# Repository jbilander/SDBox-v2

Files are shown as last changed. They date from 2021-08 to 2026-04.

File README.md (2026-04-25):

# SDBox v2
***
SDBox v2 for Amiga, hardware compatible with the new updated card-detect (insert/eject interrupt) firmware written by N.Ekström available here: https://github.com/niklasekstrom/amiga-par-to-spi-adapter

This version is superseded by the new SDBox-v3 here: https://github.com/jbilander/SDBox-v3
***

<br />
<a href="images/SDBox-v2_pic1.png">
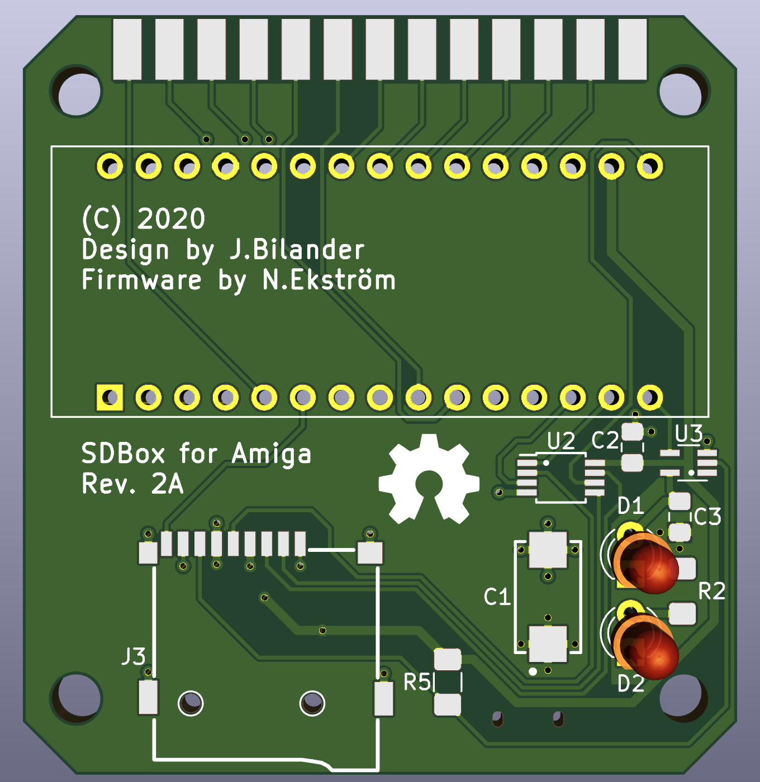
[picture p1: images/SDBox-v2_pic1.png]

</a>
<a href="images/SDBox-v2_pic2.png">
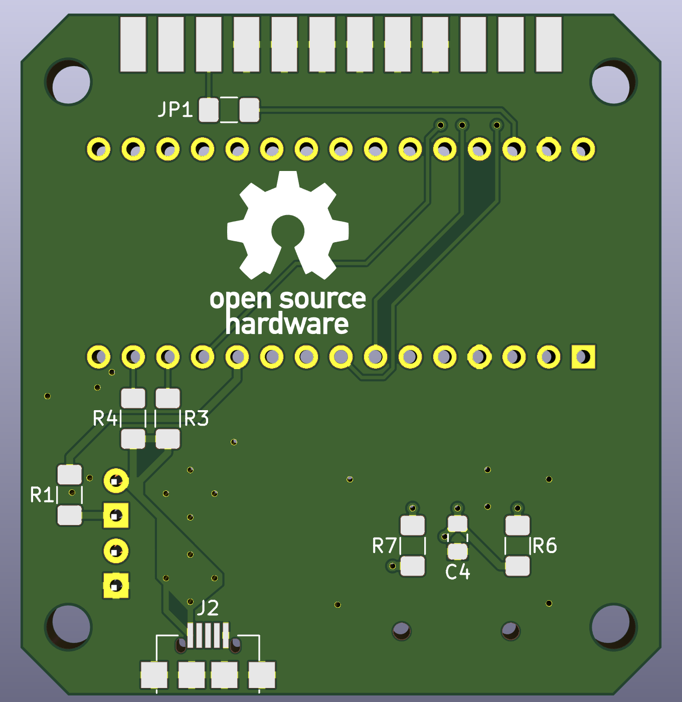
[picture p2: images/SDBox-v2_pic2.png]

</a>
<a href="images/SDBox-v2_pic3.png">
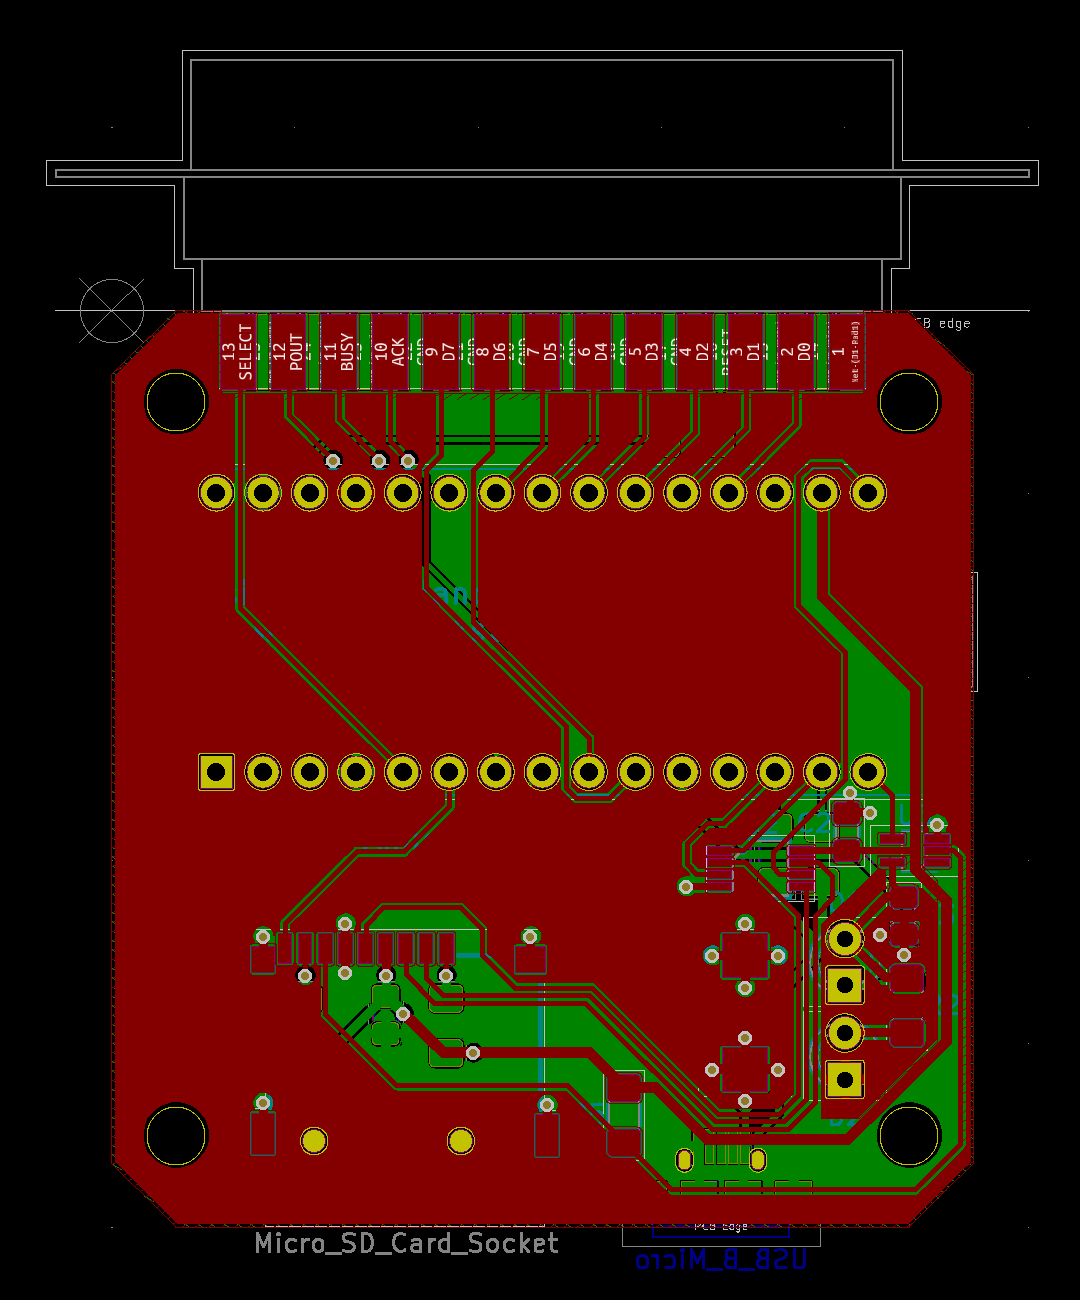
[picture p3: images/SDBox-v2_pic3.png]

</a>
<br />
<a href="images/SDBox-v2_pic4.png">
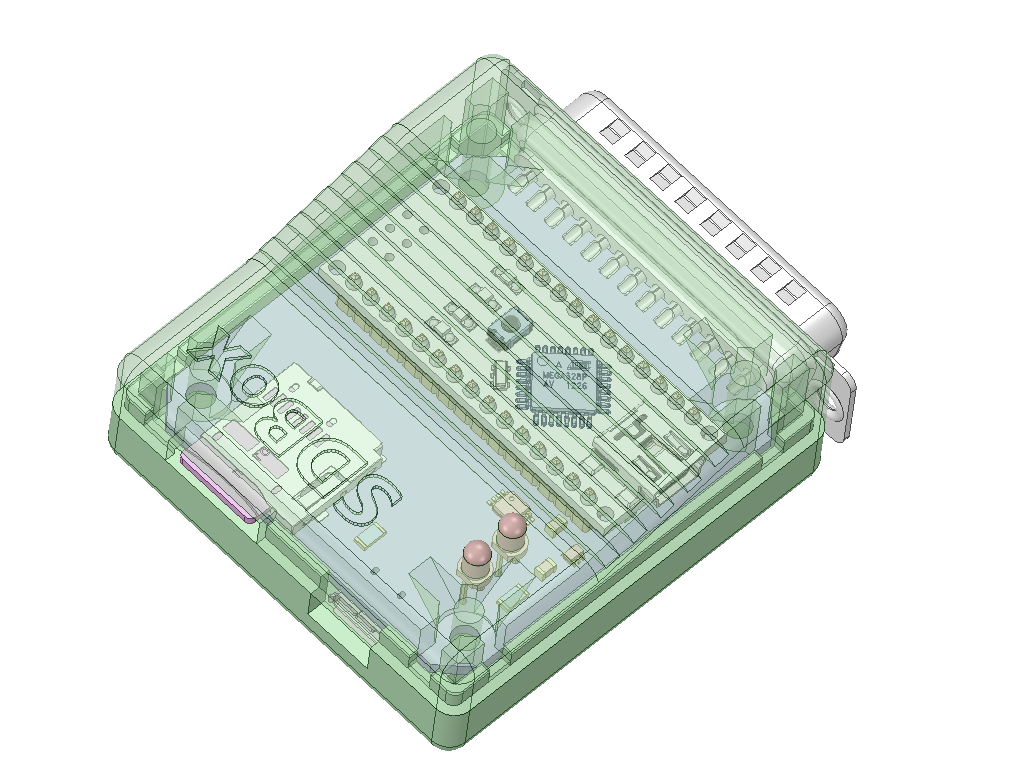
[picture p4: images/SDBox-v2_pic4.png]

</a>
<a href="images/SDBox-v2_pic5.png">
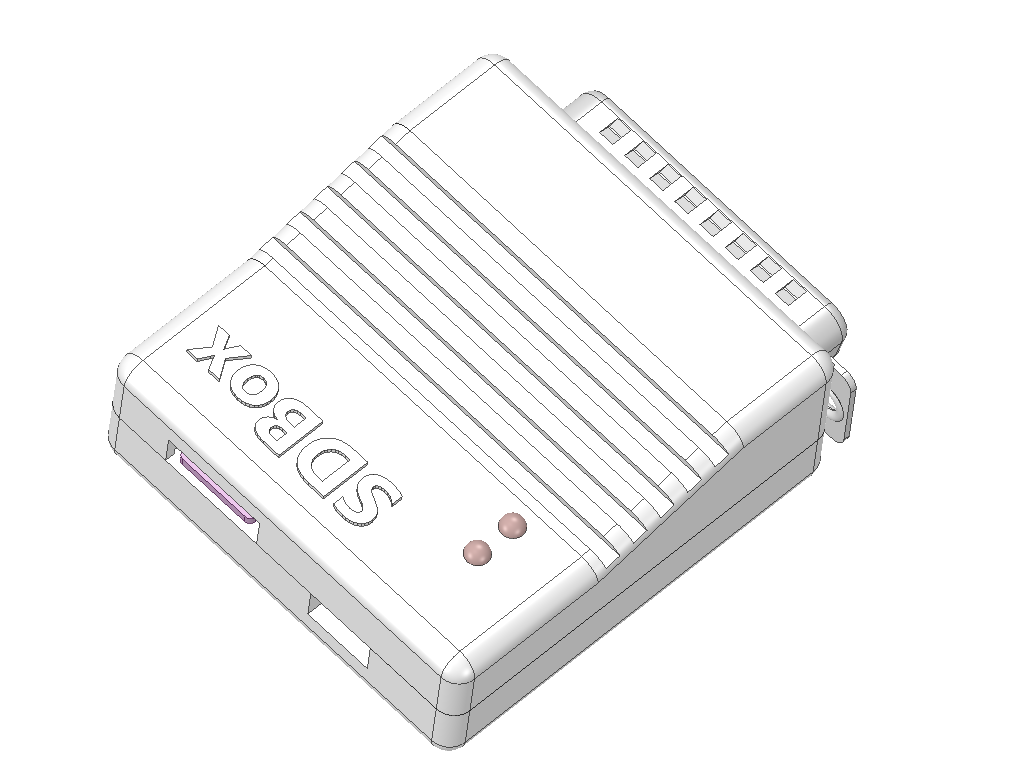
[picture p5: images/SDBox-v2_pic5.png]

</a>
<a href="images/SDBox-v2_pic6.png">
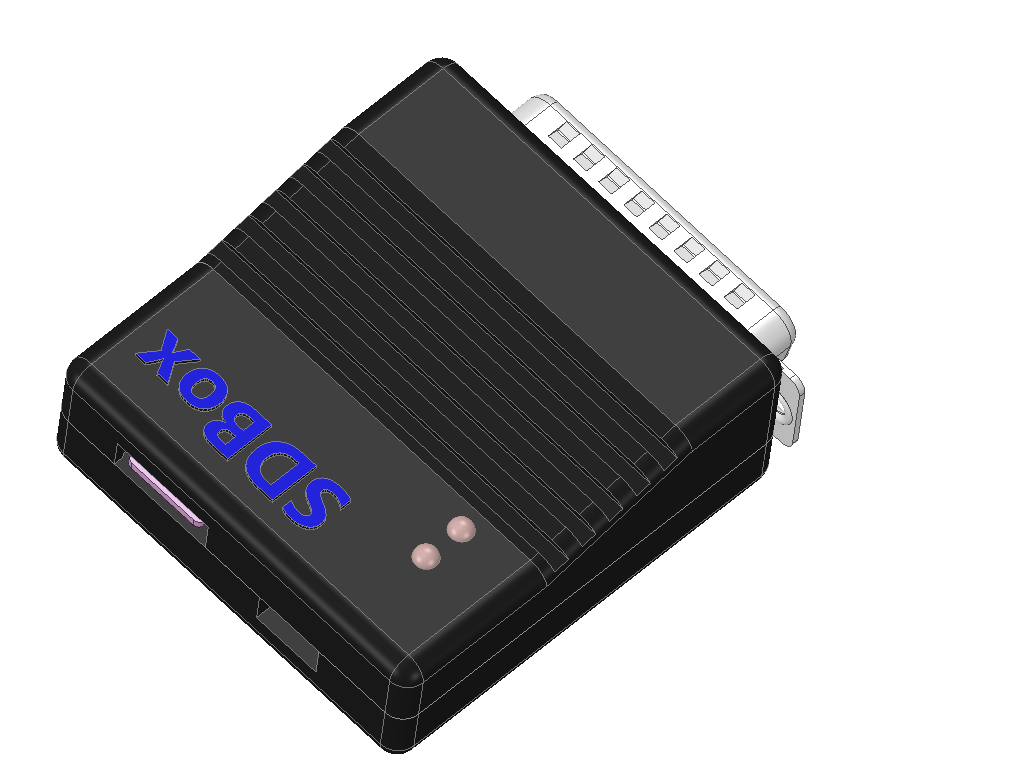
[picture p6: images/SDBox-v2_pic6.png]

</a>
<a href="images/SDBox-v2_pic7.jpg">
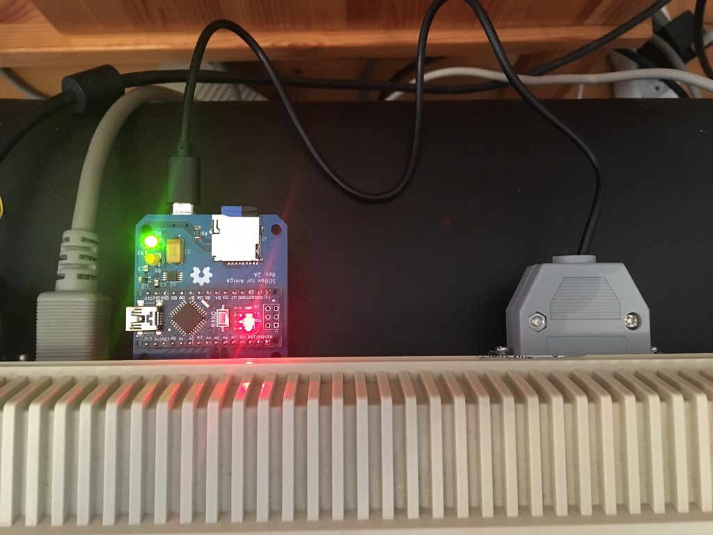
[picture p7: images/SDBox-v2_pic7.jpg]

</a>

***

Here is a short video clip showing the new card detect feature: <br />
https://drive.google.com/file/d/11R0idJcfvWwsGSfzbPFG1xpoupvCA6SC/view?usp=sharing

***

### Howto build the SDBox Rev2...

<a href="images/SDBox-v2_pic13.jpg">
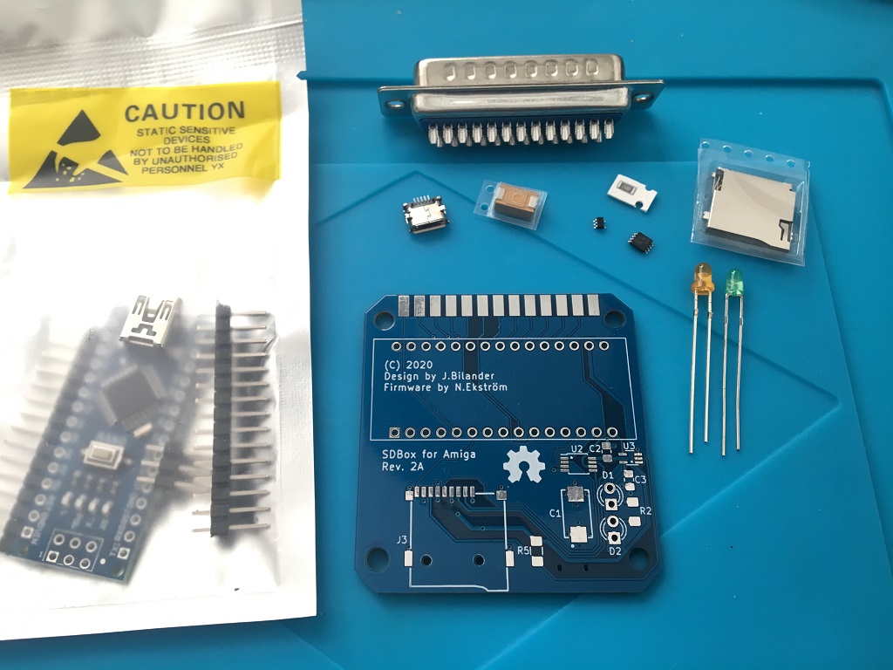
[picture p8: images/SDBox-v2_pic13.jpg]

</a>

***

Start by soldering the `U2` and `U3` ICs, then the passives, the card holder, micro-usb jack, DB25M and so on, nothing complicated, but do skip the 6-pin ICSP-header on the Nano if you're going to put this in a 3D-printed case...

***

<a href="images/SDBox-v2_pic14.jpg">
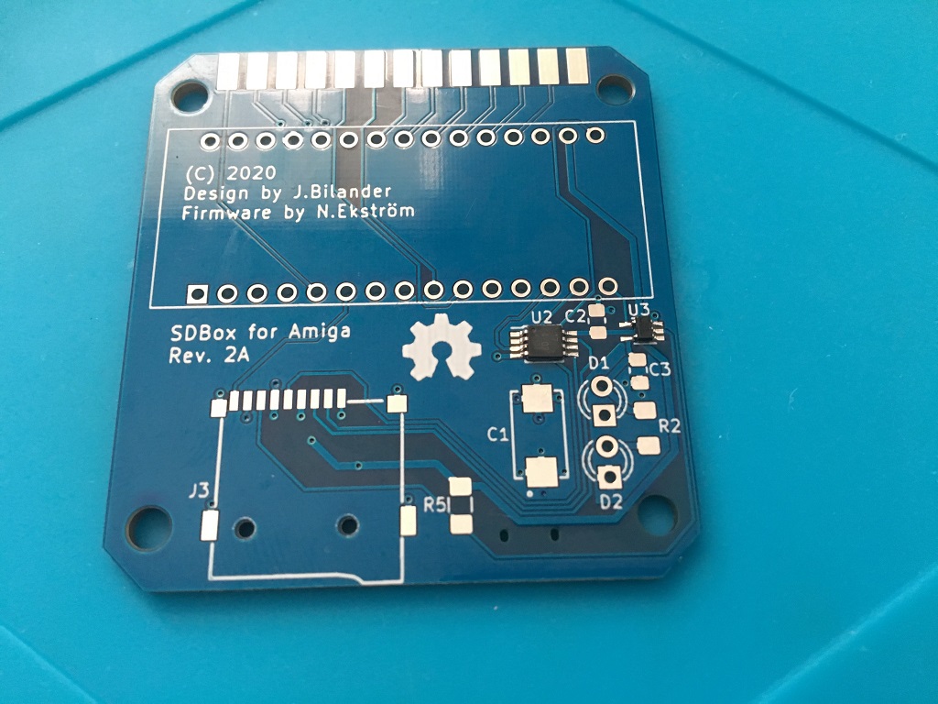
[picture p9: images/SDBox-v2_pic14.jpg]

</a>
<a href="images/SDBox-v2_pic15.jpg">
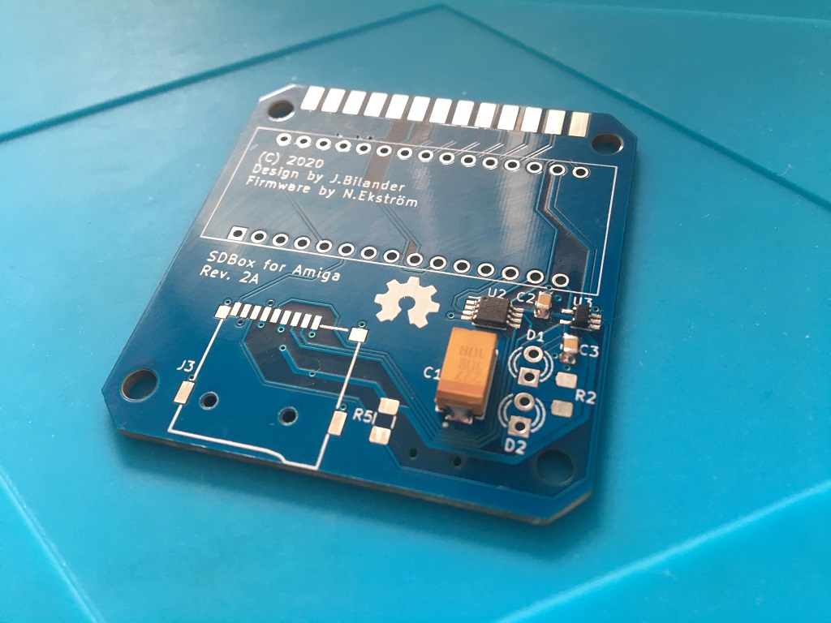
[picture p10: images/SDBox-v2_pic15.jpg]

</a>
<a href="images/SDBox-v2_pic16.jpg">
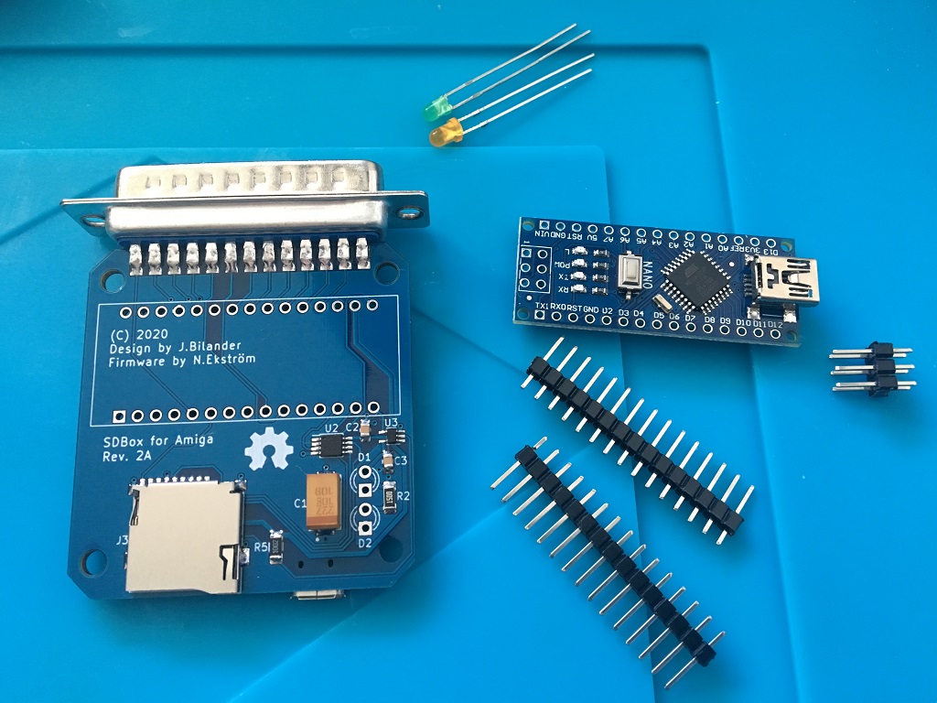
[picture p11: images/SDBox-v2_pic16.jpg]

</a>

***

At this stage, before you solder the Nano down to the board, you should verify that `+5V` via the Micro-USB jack is ok...

***

<a href="images/SDBox-v2_pic17.jpg">
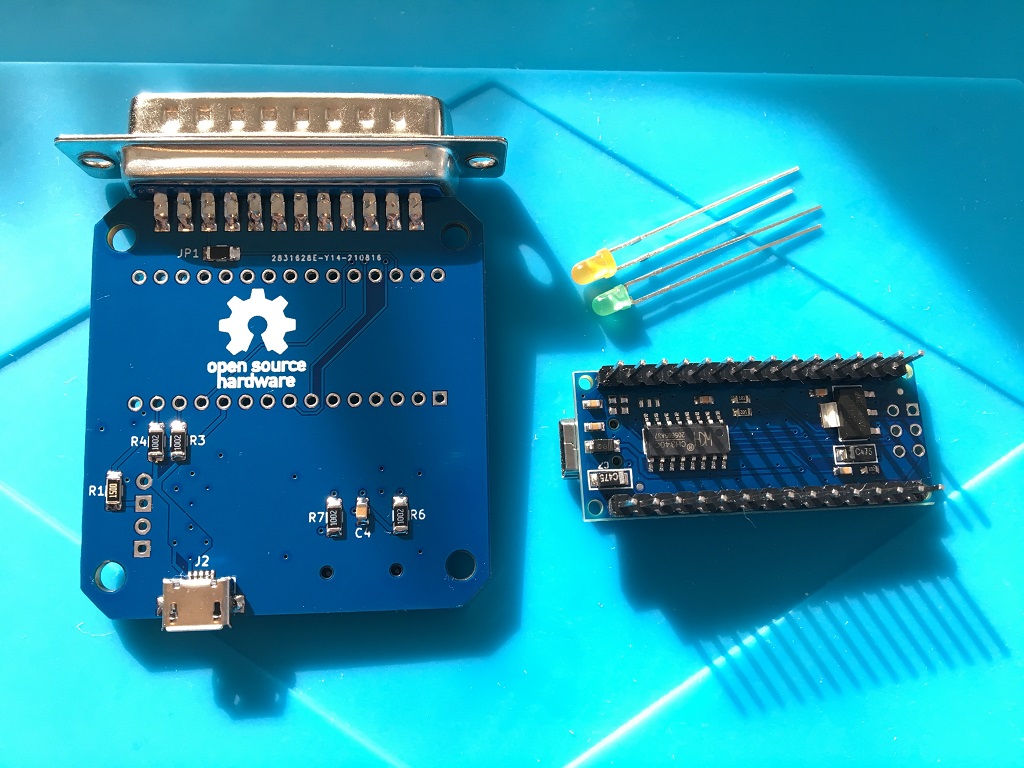
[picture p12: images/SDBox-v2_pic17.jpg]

</a>
<a href="images/SDBox-v2_pic18.jpg">
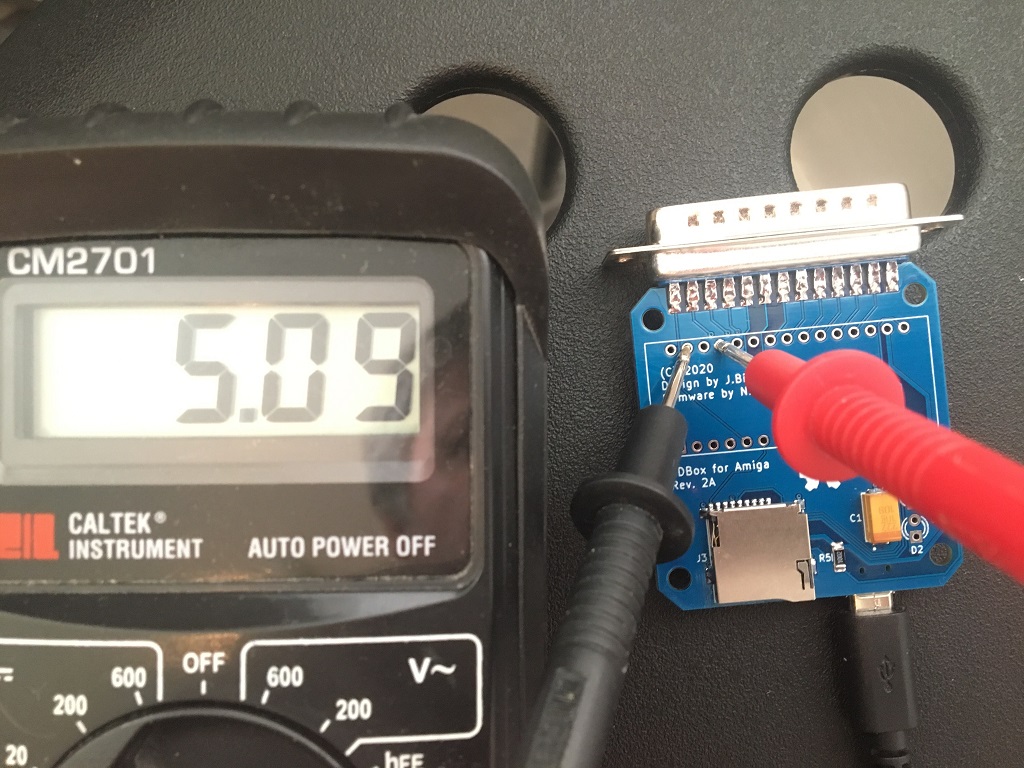
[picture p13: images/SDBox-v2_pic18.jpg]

</a>
<a href="images/SDBox-v2_pic19.jpg">
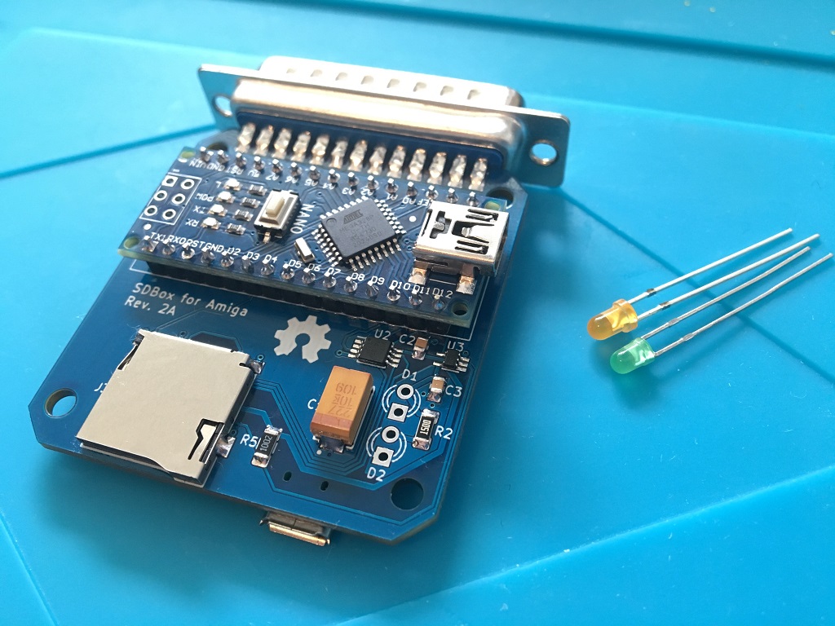
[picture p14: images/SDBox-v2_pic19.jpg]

</a>

***

Now the Nano, validate `+5V` and `+3.3V` is ok on the Nano:

Powering the MicroSD card directly from the 3.3V-pin of the Arduino, are you nuts?

Well, maybe, but typical SD card current consumption is `~30mA` in SPI mode.
The Arduino Nano taps `3.3V` from the internal LDO `3V3OUT` supply of the `FT232RL` USB-chip, or in case of the clones the `CH340` USB-chip. 

    FT232RL: Up to 50mA can be drawn from this pin to power external logic if required.
    CH340G: Maximum output current is 30mA, and that voltage stays rather stable up to about 30mA.
***

<a href="images/SDBox-v2_pic20.jpg">
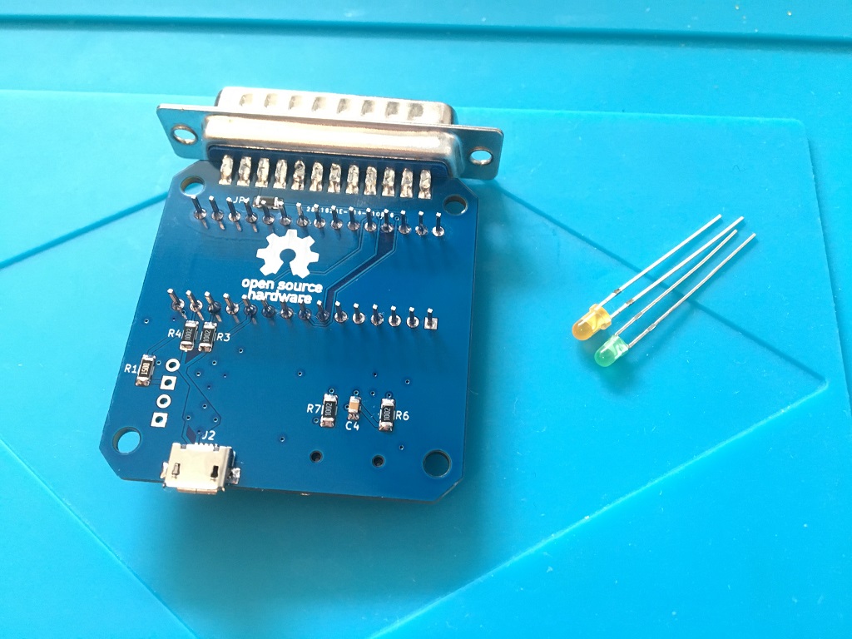
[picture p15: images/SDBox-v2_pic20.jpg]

</a>
<a href="images/SDBox-v2_pic21.jpg">
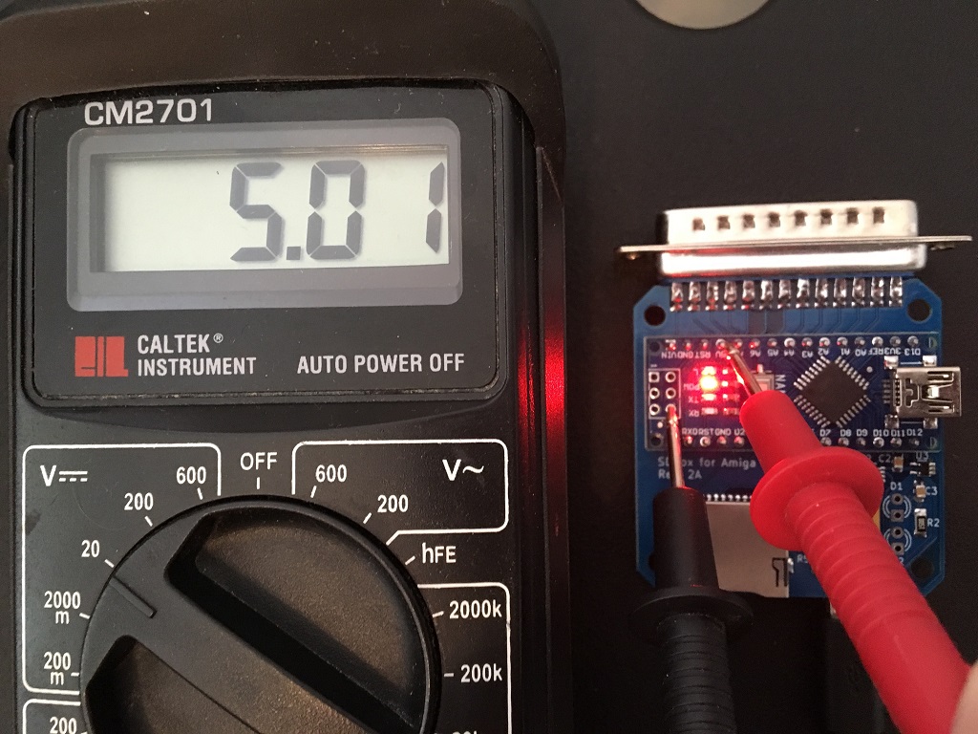
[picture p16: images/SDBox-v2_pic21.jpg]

</a>
<a href="images/SDBox-v2_pic22.jpg">
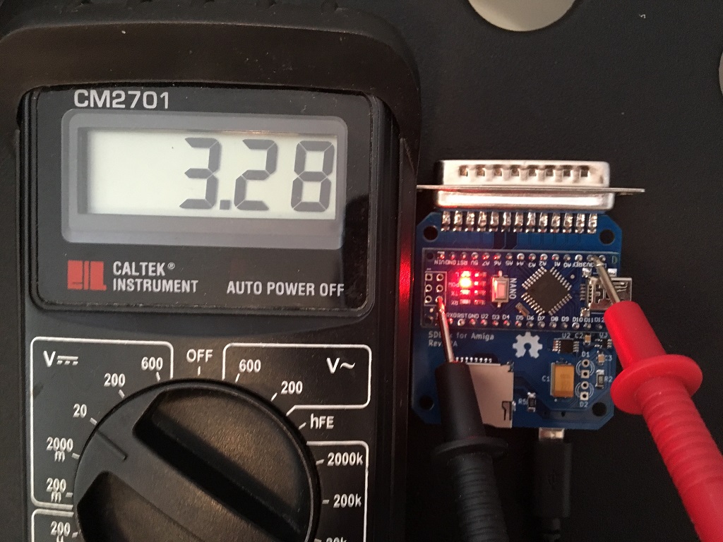
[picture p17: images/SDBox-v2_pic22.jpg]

</a>

***

Time to build and flash the firmware:

***

<a href="images/SDBox-v2_pic23.jpg">
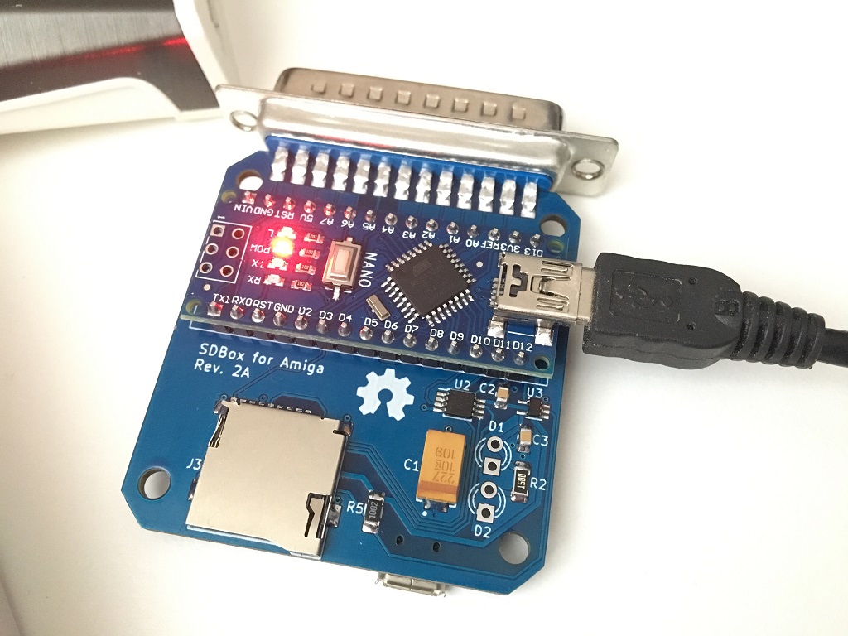
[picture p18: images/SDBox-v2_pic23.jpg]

</a>
<a href="images/SDBox-v2_flashing_Nano_pic1.jpg">
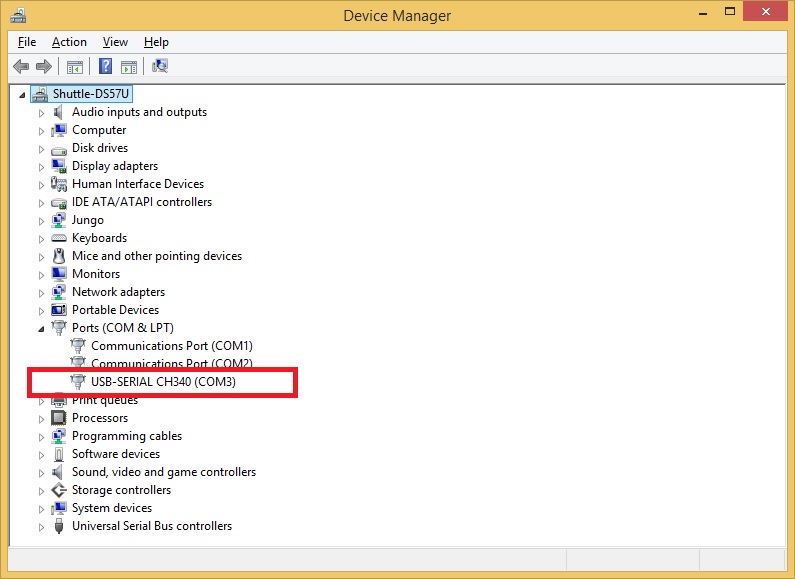
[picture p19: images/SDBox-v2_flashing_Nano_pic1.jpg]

</a>
<a href="images/SDBox-v2_flashing_Nano_pic2.jpg">
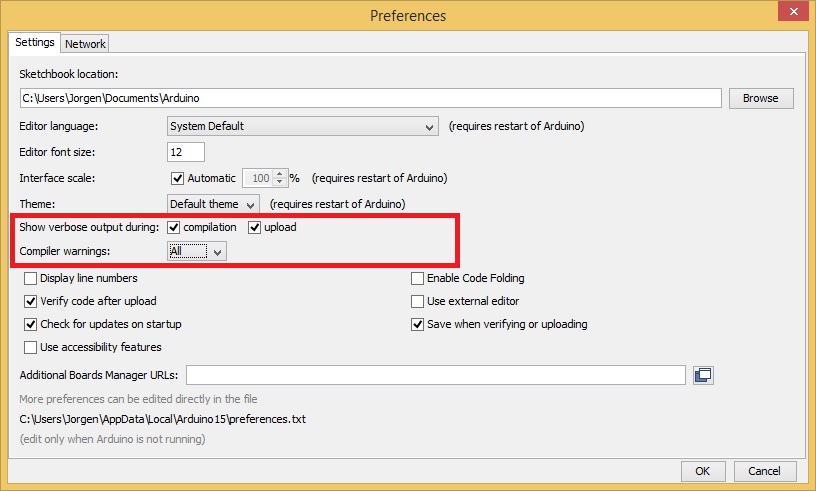
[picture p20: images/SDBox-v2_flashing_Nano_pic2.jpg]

</a>
<br />
<a href="images/SDBox-v2_flashing_Nano_pic3.jpg">
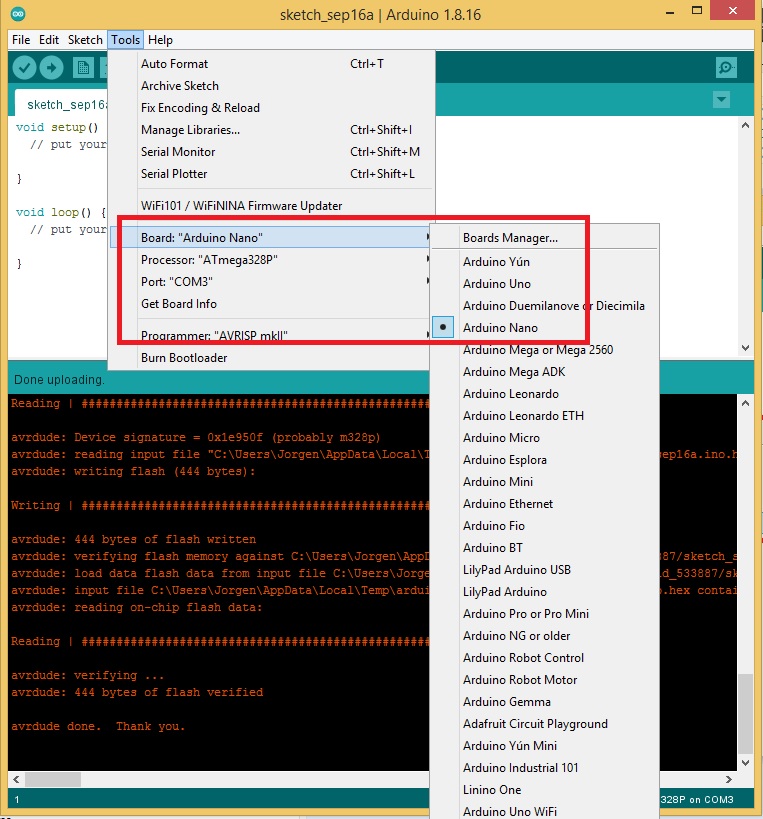
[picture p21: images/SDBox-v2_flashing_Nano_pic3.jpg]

</a>
<a href="images/SDBox-v2_flashing_Nano_pic4.jpg">
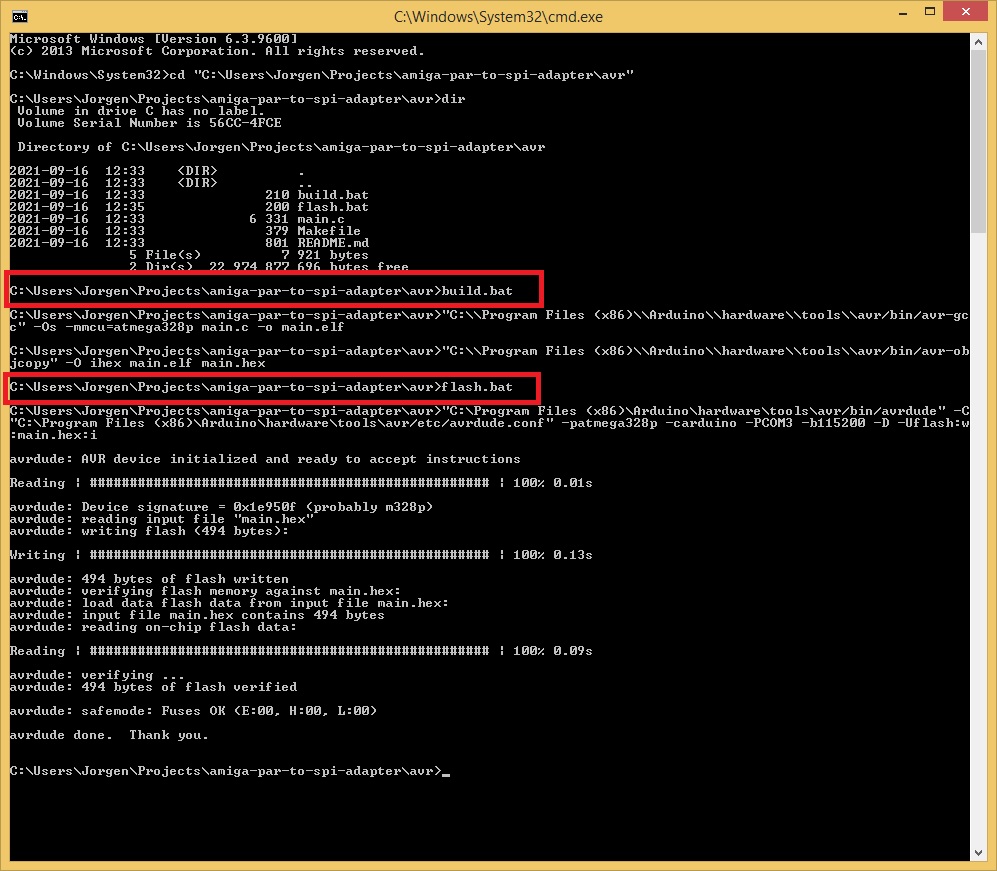
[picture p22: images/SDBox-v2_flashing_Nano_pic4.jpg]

</a>

***

And we need to 3D-print a case for it before we put the LEDs in, don't we?...

(STL-files available in the DSM folder)

***

<a href="images/SDBox-v2_pic24.jpg">
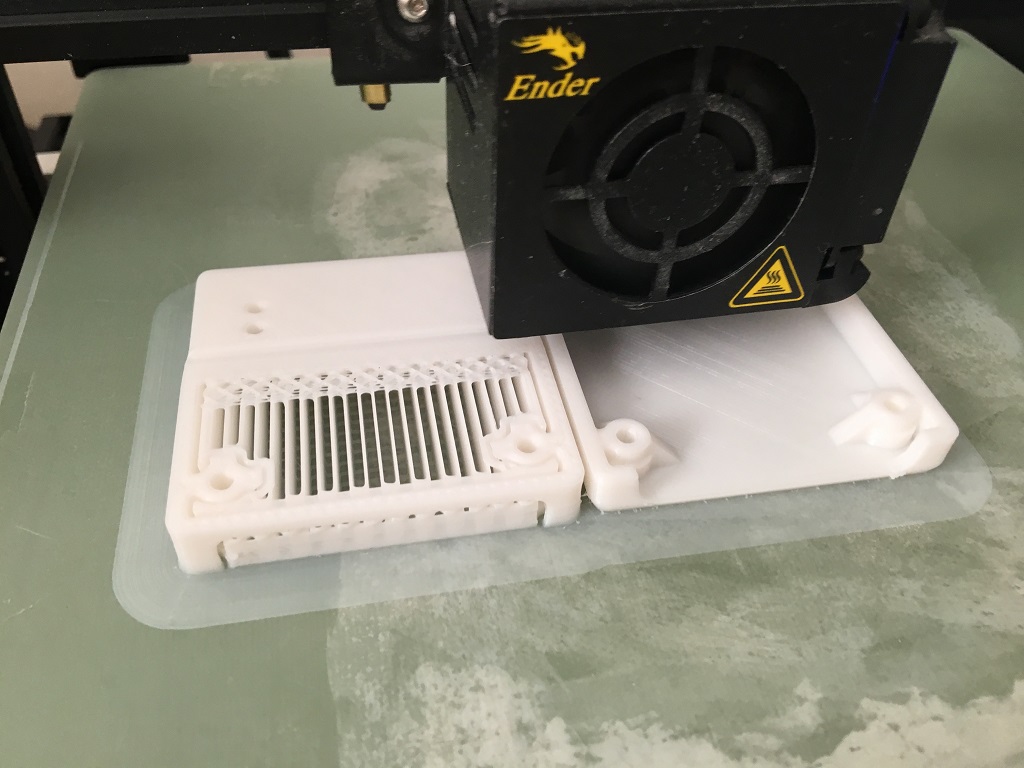
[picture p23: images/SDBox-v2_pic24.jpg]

</a>
<a href="images/SDBox-v2_pic25.jpg">
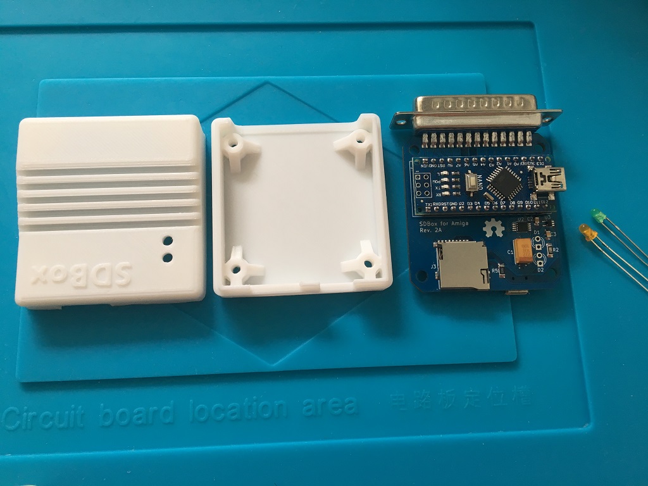
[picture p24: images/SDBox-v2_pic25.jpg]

</a>
<a href="images/SDBox-v2_pic26.jpg">
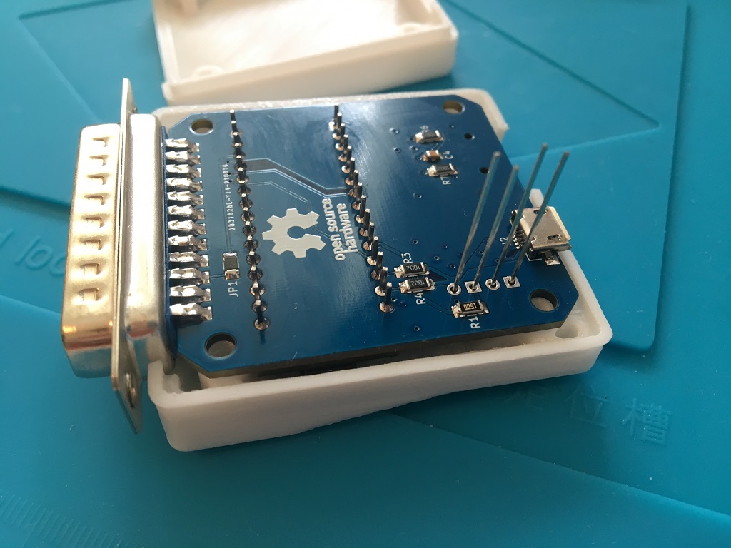
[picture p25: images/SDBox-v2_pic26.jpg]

</a>

***

Final result:
<br />
<a href="images/SDBox-v2_pic9.jpg">
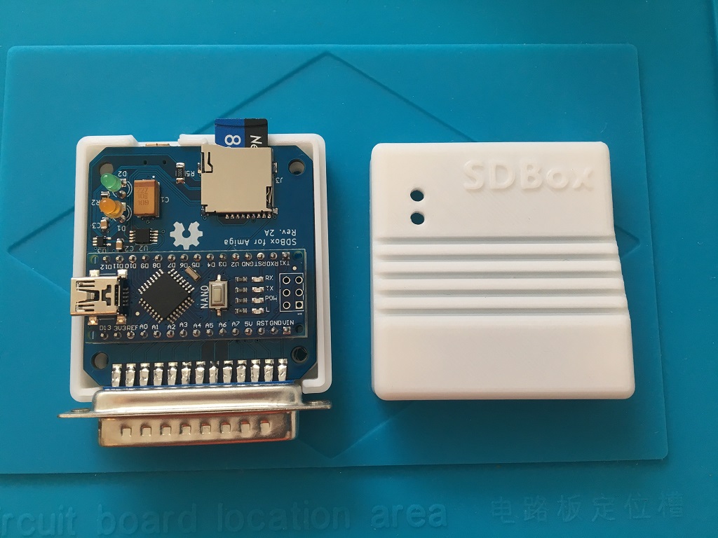
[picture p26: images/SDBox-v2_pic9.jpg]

</a>
<a href="images/SDBox-v2_pic10.jpg">
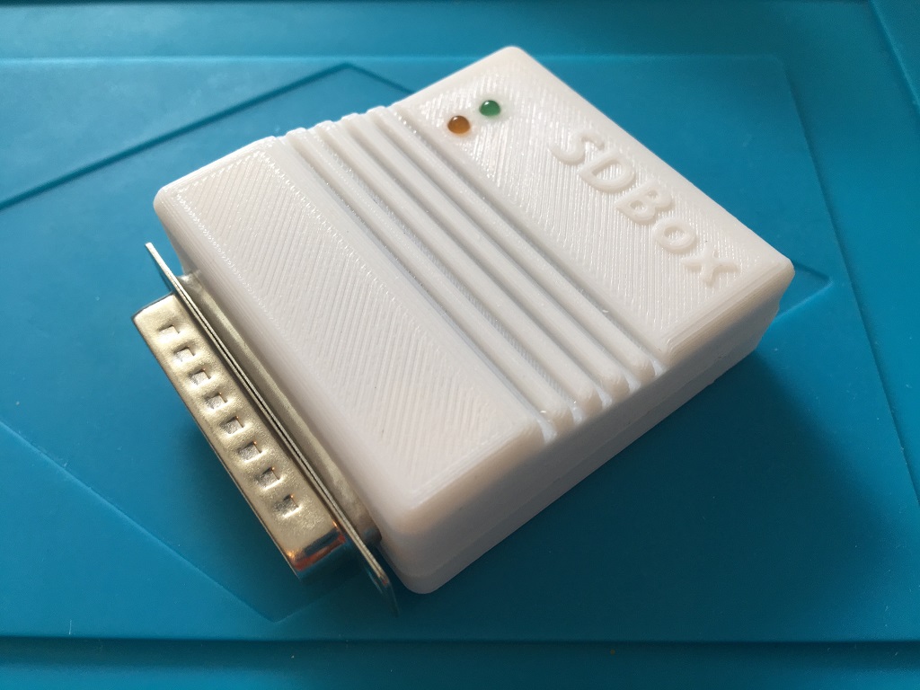
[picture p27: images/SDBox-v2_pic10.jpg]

</a>
<a href="images/SDBox-v2_pic11.jpg">
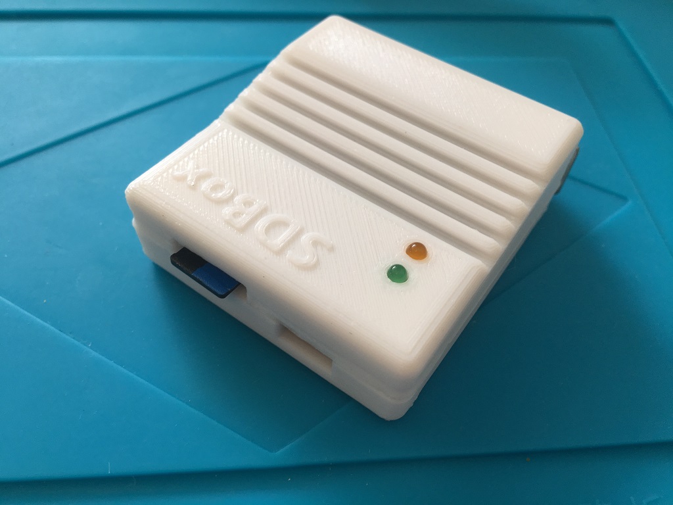
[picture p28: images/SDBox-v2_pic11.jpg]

</a>
<a href="images/SDBox-v2_pic12.jpg">
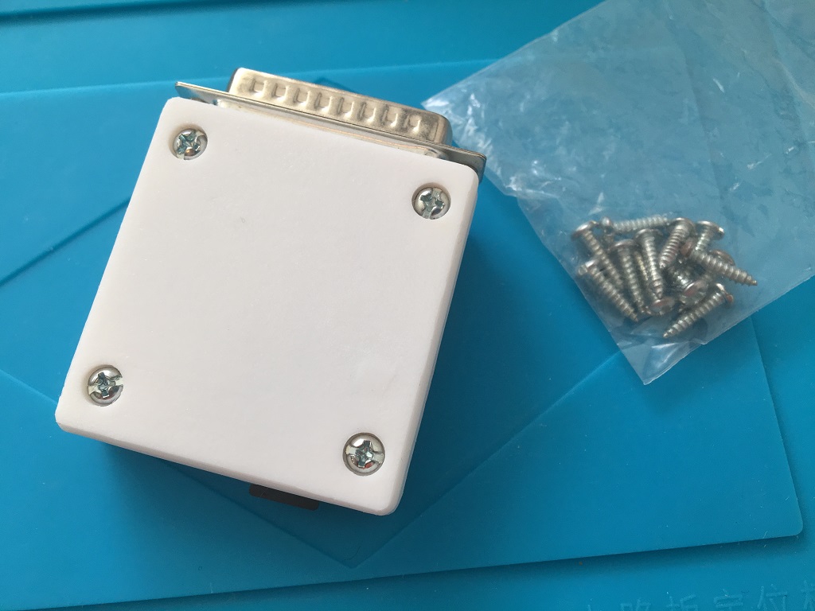
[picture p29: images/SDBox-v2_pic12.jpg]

</a>

***

Comparison with `v1`, look at the difference in size:
<br />
<a href="images/SDBox-v2_pic27.jpg">
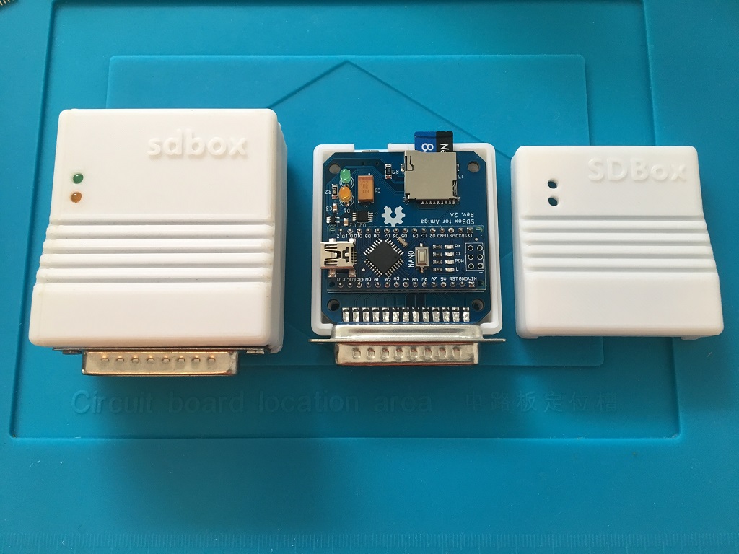
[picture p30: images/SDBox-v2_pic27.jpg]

</a>
<a href="images/SDBox-v2_pic28.jpg">
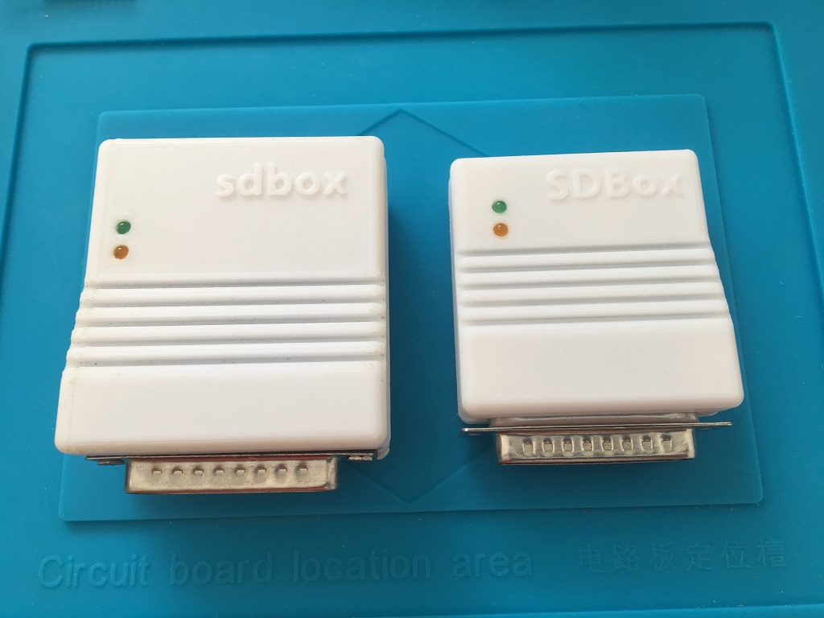
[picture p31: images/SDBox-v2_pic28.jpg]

</a>
<a href="images/SDBox-v2_pic29.jpg">
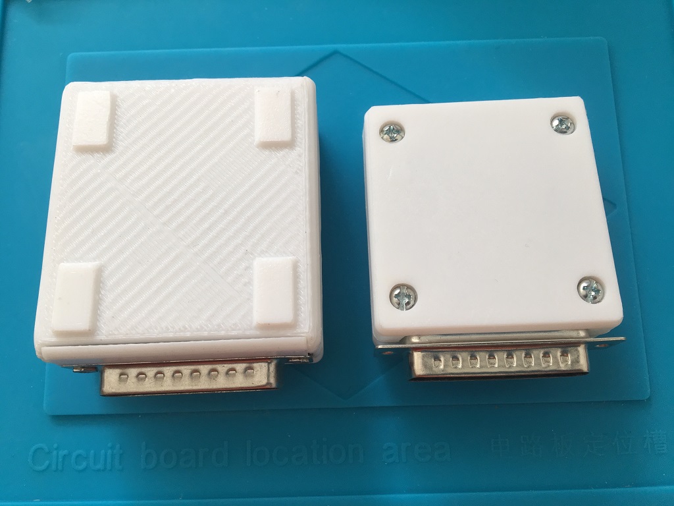
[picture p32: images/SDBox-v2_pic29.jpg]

</a>
<a href="images/SDBox-v2_pic30.jpg">
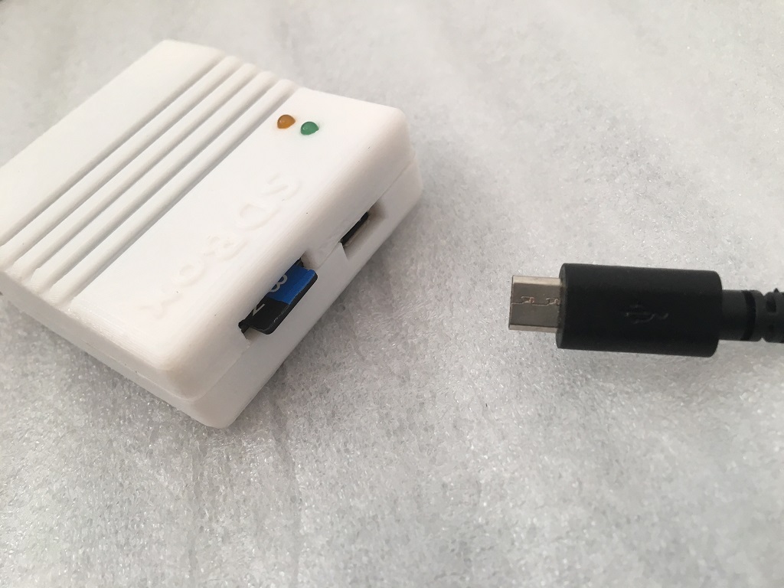
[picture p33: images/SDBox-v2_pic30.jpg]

</a>

***

Now time to build the new `spisd.device` driver, add `+kick13` to the `build.bat` if default is set to build for AmigaOS 2.0...

(`VBCC` for Windows I downloaded from here (Thanks: Leffmann for the installer), https://eab.abime.net/showthread.php?t=83113 )

***

<a href="images/SDBox-v2_VBCC_pic1.jpg">
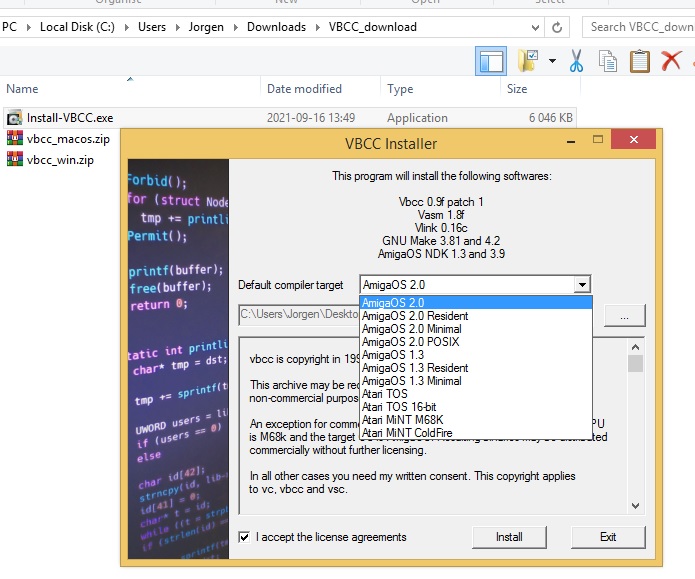
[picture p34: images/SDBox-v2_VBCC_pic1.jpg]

</a>
<a href="images/SDBox-v2_VBCC_pic2.jpg">
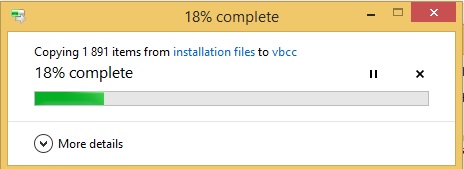
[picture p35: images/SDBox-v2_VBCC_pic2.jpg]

</a>
<a href="images/SDBox-v2_VBCC_pic3.jpg">
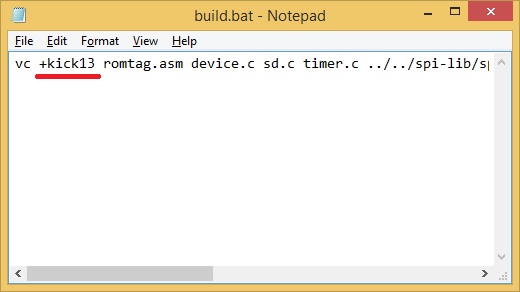
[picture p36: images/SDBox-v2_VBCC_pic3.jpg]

</a>
<a href="images/SDBox-v2_VBCC_pic4.jpg">
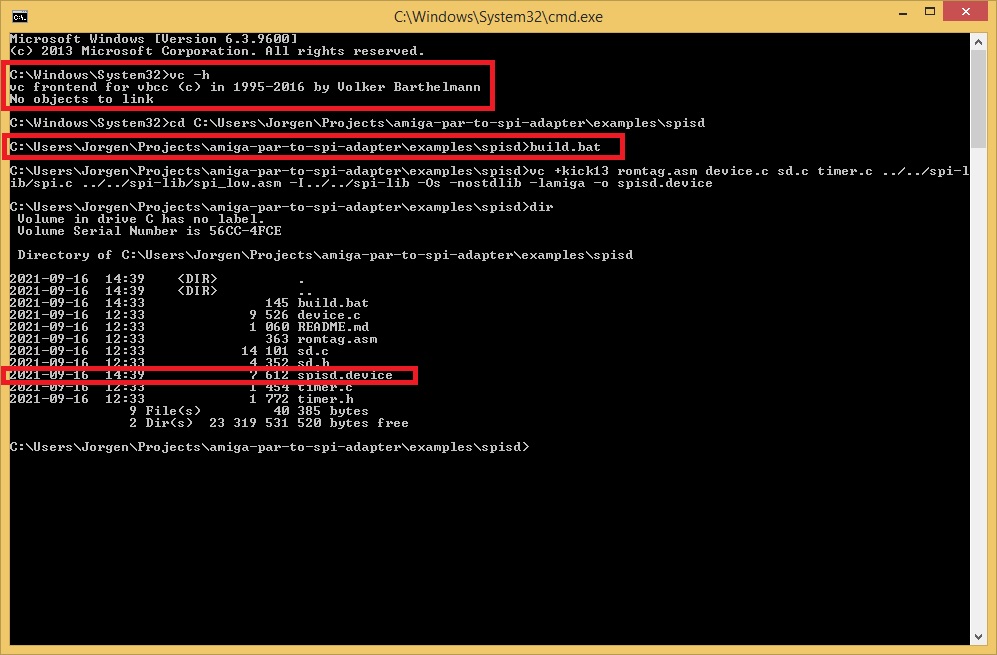
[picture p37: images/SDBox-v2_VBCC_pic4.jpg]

</a>

***

BOM Rev. 2A
---------
Position  | Name/Value   | Package | Notes
-|-|-|-|
U1 | Arduino Nano V3 | |
U2 | 74LVC3G17 | TSSOP-8_3x3mm_P0.65mm | Triple non-inverting Schmitt trigger with 5V tolerant input [74LVC3G17](https://www.mouser.com/ProductDetail/771-LVC3G17DP125)
U3 | 74AHCT1G17 | 5-TSSOP, SC-70-5, SOT-353  (2.0 mm × 1.25mm) | Single non-inverting Schmitt trigger [74AHCT1G17GWH](https://www.mouser.com/ProductDetail/771-74AHCT1G17GWH)
J1 | D-Sub DB25M | DB25 Male connector with solder lugs | DB25 for Amiga parallel port
J2 | Micro USB connector | USB Micro B SMT | For +5V Power, (style 1) <br />https://www.aliexpress.com/item/32991869539.html
J3 | Micro SD Card Holder | 9-pin Micro SD card slot connector | https://www.aliexpress.com/item/32802051702.html
D1 (Optional) | LED 3mm | PinHeader_1x02_P2.54mm_Vertical, pin pitch 2.54 mm | SD Activity LED indicator, Diffused Orange / Amber, 1.8V-2.3V, 20-30 mA, 605-610nm
D2 (Optional) | LED 3mm | PinHeader_1x02_P2.54mm_Vertical, pin pitch 2.54 mm | Power LED indicator, Green Diffused T-1, 25 mcd, 565 nm, 2.2 V, 25 mA
R1 (Optional) | 150 Ohm Resistor | 1206 SMD, 200 mW | (Mandatory if D1 populated) Series resistor for D1 LED, adjust R-value to your type of LED and preferred brightness
R2 (Optional) | 150 Ohm Resistor | 1206 SMD, 200 mW | (Mandatory if D2 populated) Series resistor for D2 LED, adjust R-value to your type of LED and preferred brightness
R3 | 10k Ohm Resistor | 1206 SMD | Pull-up (to VCC) resistor for /SS
R4 (Optional) | 10k Ohm Resistor | 1206 SMD | Pull-up (to VCC) resistor for MOSI
R5 | 10k Ohm Resistor | 1206 SMD | Pull-up (to 3V3) for MISO_3V3
R6 | 10k Ohm Resistor | 1206 SMD | Pull-up (to 3V3) for DAT1 pin 8 on MicroSD-holder
R7 | 10k Ohm Resistor | 1206 SMD | Pull-up (to 3V3) for DAT2 pin 1 on MicroSD-holder
JP1 (Optional) | 0 Ohm Resistor, or Solder Blob | 1206 SMD | Populate this one to reset Nano in conjunction with Ctrl-Amiga-Amiga
C1 | 220uF Capacitor | SMD-Tantalum, 4.3 x 7.3 x 2.8 mm | Capacitor for VIN +5V Power via USB https://www.reichelt.com/se/en/smd-tantalum-220-f-10v-125-c-t491d-220u-10-p206492.html
C2 | 0.1uF = 100nF Capacitor | 0805 SMD | Decoupling capacitor for U2
C3 | 0.1uF = 100nF Capacitor | 0805 SMD | Decoupling capacitor for U3
C4 | 0.1uF = 100nF Capacitor | 0805 SMD | Decoupling capacitor for J3

***

### Howto get 5V from the Amigas external floppy port _(250 mA max)_, let's make a cable...

<br />
<a href="images/SDBox_get_5V_from_external_floppy_port_cable_pic1.jpg">
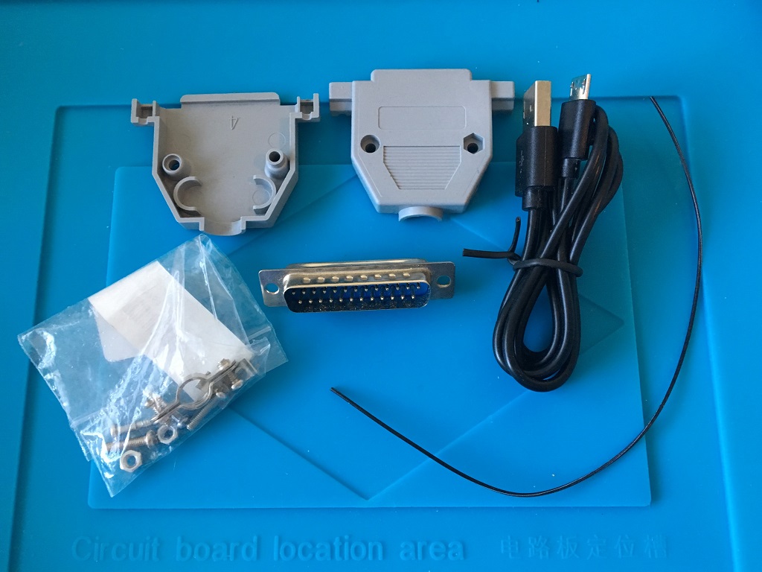
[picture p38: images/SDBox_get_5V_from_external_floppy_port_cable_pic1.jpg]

</a>
<a href="images/SDBox_get_5V_from_external_floppy_port_cable_pic14.jpg">
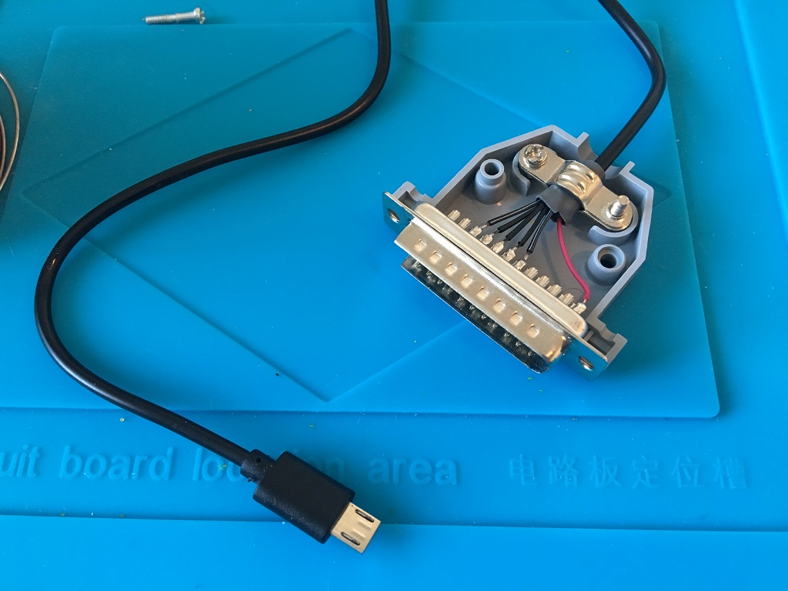
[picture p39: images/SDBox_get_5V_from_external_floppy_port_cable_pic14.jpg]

</a>
<a href="images/SDBox_get_5V_from_external_floppy_port_cable_pic15.jpg">
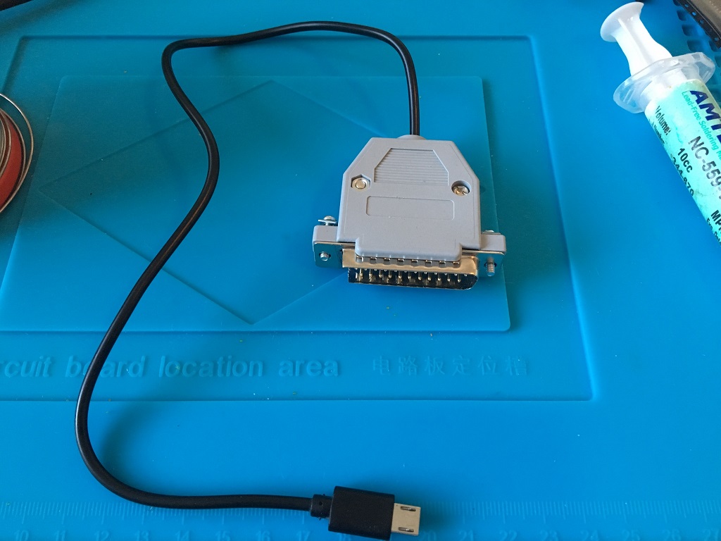
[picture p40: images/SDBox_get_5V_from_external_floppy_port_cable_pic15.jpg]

</a>

***
I did't have a `DB23` Male connector so I used a `DB25` and cut it down to a 23 with a hacksaw. I cut on the left side (pin 1 and 14) so that the plug will clear the neighbouring RCA-jack when plugged into the A500 external floppy drive port.
***

<a href="images/SDBox_get_5V_from_external_floppy_port_cable_pic2.jpg">

</a>
<a href="images/SDBox_get_5V_from_external_floppy_port_cable_pic3.jpg">

</a>
<a href="images/SDBox_get_5V_from_external_floppy_port_cable_pic4.jpg">

</a>

***
Remove pin 1 and 14, wiggle back and forth with a plier until they exhaust and snap then pull out the remains from the other side
***

<a href="images/SDBox_get_5V_from_external_floppy_port_cable_pic5.jpg">

</a>
<a href="images/SDBox_get_5V_from_external_floppy_port_cable_pic6.jpg">

</a>
<a href="images/SDBox_get_5V_from_external_floppy_port_cable_pic7.jpg">

</a>

***
Cut and wirestrip the micro-usb cable. Verify polarity, normally black is GND and red is +5V but the cable mfg might have mixed up the wire colours so check with a multimeter to be certain. Pin 3-7 on the connector is GND on the Amiga, +5V is on pin 12. You could either Blob pin 3-7 together (requires quite a lot of solder) and then solder the micro-usb GND-wire to that Blob or do as I did below with 5 individual wires soldered and crimped together.
***

<a href="images/SDBox_get_5V_from_external_floppy_port_cable_pic8.jpg">

</a>
<a href="images/SDBox_get_5V_from_external_floppy_port_cable_pic9.jpg">

</a>
<a href="images/SDBox_get_5V_from_external_floppy_port_cable_pic10.jpg">

</a>

***
Some shrink tube on, a bit overkill maybe but hey it's a guide, no shortcuts, I even crimped AND soldered the GND-joint :)
***

<a href="images/SDBox_get_5V_from_external_floppy_port_cable_pic11.jpg">

</a>
<a href="images/SDBox_get_5V_from_external_floppy_port_cable_pic12.jpg">

</a>
<a href="images/SDBox_get_5V_from_external_floppy_port_cable_pic13.jpg">

</a>

***
Ready to go and it clears both the RCA-plug and the serial port connector. With this cable now plugged into the SDBox it'll be powered on as soon as the Amiga is powered on and vice versa.
***

<a href="images/SDBox_get_5V_from_external_floppy_port_cable_pic14.jpg">

</a>
<a href="images/SDBox_get_5V_from_external_floppy_port_cable_pic15.jpg">

</a>
<a href="images/SDBox_get_5V_from_external_floppy_port_cable_pic16.jpg">

</a>

***

Happy Hackin'

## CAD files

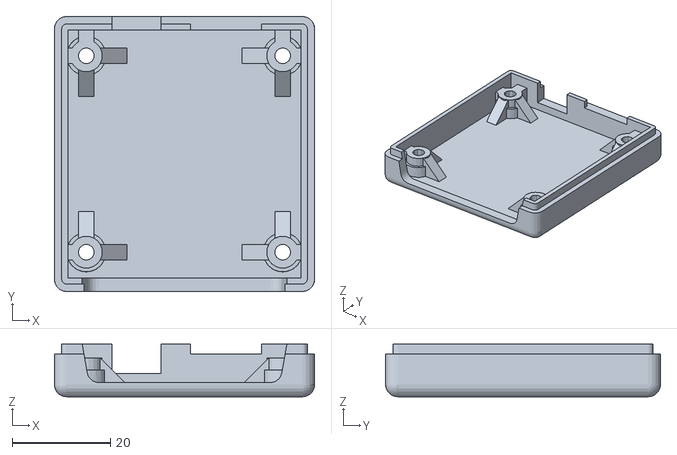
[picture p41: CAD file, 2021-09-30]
DSM/SDBox-v2_case_bottom.stl
53.0 x 56.0 x 10.7

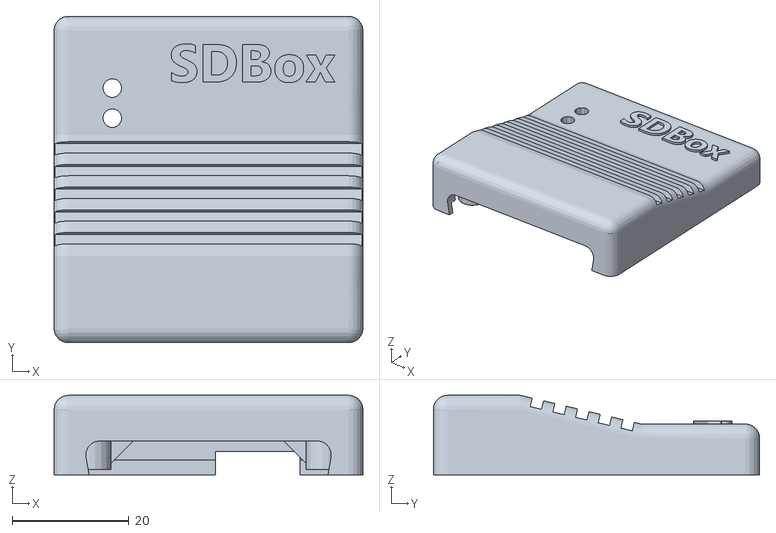
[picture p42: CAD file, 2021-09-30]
DSM/SDBox-v2_case_top.stl
53.0 x 56.0 x 13.6

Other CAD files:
DSM/SDBox-v2_text.skp

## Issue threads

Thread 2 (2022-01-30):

Firmware issues

hickachu, 2022-01-30:
When I use your firmware 0.4 hex or compiled from your fork, I am unable to mount the sd0. I get no error from the mount command but when I try to access sd0: I get "Bad number" error from the amiga. If the sdcard is in the sdbox v2 from cold boot the machine goes into a reset boot loop.
I see no activity from the nano when the sdcard is inserted or ejected.

When I use original firmware from Niklas Ekström the sdbox V2 works as it should, minus any activity light for obvious reasons.

I have built several of the units and it is the exact same on all units. Any idea what the "issue" could be?

jbilander, 2022-01-30:
Hi,

Firmware v0.4 is for the old sdbox Rev 1. It's not compatible with Rev 2, pinout assignments is different on Rev 2...You can use my fork of Niklas's firmware to build a hex with support for activity led for v2:

https://github.com/jbilander/amiga-par-to-spi-adapter

Regards, J

hickachu, 2022-01-30:
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

Sorry, I should have mentioned I did try that version, same results.

jbilander, 2022-01-30:
Hi, you mentioned it works with Niklas' firmware. My fork is the exact same code as his except these lines are added to enable the activity led.

https://github.com/jbilander/amiga-par-to-spi-adapter/commit/aeaf351bd57fc0b75dae18e1f8b91ef14cbc8c00

Retro-updates, 2022-05-04:
Hello, I'm getting SD0: Unreadable after mounting on AmigaOS. (Rev 2A SDBox with new spisd.device driver)
What  could i be doing wrong here?

jbilander, 2022-05-04:
Hi, did you build and flash the Arduino Nano with the updated firmware from here?
https://github.com/jbilander/amiga-par-to-spi-adapter/tree/master/avr

Retro-updates, 2022-05-04:
I programmed the nano with the v2 firmware;

Retro-updates, 2022-05-05:
> I programmed the nano with the v2 firmware;
> https://github.com/niklasekstrom/amiga-par-to-spi-adapter/releases/tag/v2.0
> and used the spisd.device from the same page

I programmed (make+flash) the nano with the v2 firmware;
https://github.com/niklasekstrom/amiga-par-to-spi-adapter/releases/tag/v2.0
and used the spisd.device from the same page

Retro-updates, 2022-05-05:
> Hi, did you build and flash the Arduino Nano with the updated firmware from here? https://github.com/jbilander/amiga-par-to-spi-adapter/tree/master/avr

I programmed (make+flash) the nano with the v2 firmware;
https://github.com/niklasekstrom/amiga-par-to-spi-adapter/releases/tag/v2.0
and used the spisd.device from the same page

jbilander, 2022-05-06:
Try with these files, they work for me, you need to copy to appropriate places...
[SDBox_v2_files.zip](https://github.com/jbilander/SDBox-v2/files/8638658/SDBox_v2_files.zip)

Retro-updates, 2022-05-06:
> Try with these files, they work for me, you need to copy to appropriate places... [SDBox_v2_files.zip](https://github.com/jbilander/SDBox-v2/files/8638658/SDBox_v2_files.zip)

Thanks. I have copied the files you've send to my wb3.1 environment, but when i launch SD0 mount icon, i get error message: 'SD0:' is not a valid keyword. (file 'SD0', line 1, comulm 1)

Retro-updates, 2022-05-07:
> Try with these files, they work for me, you need to copy to appropriate places... [SDBox_v2_files.zip](https://github.com/jbilander/SDBox-v2/files/8638658/SDBox_v2_files.zip)

At which moment do i need to see the activity led of the SDBox showing activity?
I only see the power led active at this moment.
The activity led is not on if i insert an SD or if i try to mount.

jbilander, 2022-05-07:
Hi, You need to build and flash the firmware from my fork if you want activity led support. I mention this in my first comment.
Activity LED will start to blink when you mount the drive. SD0-file is supposed to be placed into Devs-folder or you can change the location in the Mount-script and save the file, it does this:

```
cd devs:
mount SD0: from SD0
cd SD0:
quit
```

With KS 3.1/WB 3.1 and later I think you can remove the first line in the SD0-file (the SD0: part) and save the file, and then just double-click the SD0-icon to mount:

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

Retro-updates, 2022-05-07:
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

Thanks again for the information.
I've placed the SDO file in devs and removed the first line SD0:

Contents:
FileSystem     = l:fat95
Device         = spisd.device
Unit           = 0
Flags          = 0
LowCyl         = 0
HighCyl        = 0
Surfaces       = 1
BlocksPerTrack = 1
BlockSize      = 512
Reserved       = 0
Buffers        = 20
BufMemType     = 1
BootPri        = 0
StackSize      = 4096
Priority       = 5
GlobVec        = -1
DosType        = 0x46415401
#

When i try to mount SD0 from CLI i get error message: ERROR: Device 'SD0' not fond in file SD0

Retro-updates, 2022-05-07:
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

Additional information:
If i leave the SD0: to start the contents of the SD0 file, and use your fork to flash the nano, the activity led does go up a short moment when i mount the SD0. Only when i try to access it by going to the drive (CD SD0;) i get error message : Not a valid DOS disk. I've created a small <2GB partition on the MicroSD with Fat and Fat32)

jbilander, 2022-09-01:
Hi,

Salocinx has done some excellent SDBox-testing and found and fixed a bug in the V2-driver, you might want to try out if this fix helps with your issue as well.

This fix:
https://github.com/niklasekstrom/amiga-par-to-spi-adapter/commit/30736877bd1a5e277b54d2e37395fe8800dbba40

I have merged his fix (from upstream) into my fork as well now:
https://github.com/jbilander/amiga-par-to-spi-adapter

Regards

Retro-updates, 2022-09-01:
Thanks for sharing!
I will test the new driver and share my findings.

Retro-updates, 2022-09-02:
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

Do i need to compile the Amiga driver spisd.device only, or is a firmware flash for the arduino also needed?
Can you attach a compiled version of the driver here?

Retro-updates, 2022-09-07:
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

Flashed a arduino with v2 firmware for a SDBOX 2.
Used same amiga OS device driver.
MicroSD card is mounted correctly, but during write attemps i get write errors.
Is there a specific partition size for the Amiga advised?

jbilander, 2022-09-07:
Hi,
The fix is only on the Amiga side. You need to build a new _spisd.device_ and replace the one you have in Devs:
Instructions/pics for this is just above the BOM here https://github.com/jbilander/SDBox-v2/#bom-rev-2a
Firmware is the same as before.
Regards

Retro-updates, 2022-09-07:
> Hi, The fix is only on the Amiga side. You need to build a new _spisd.device_ and replace the one you have in Devs: Instructions/pics for this is just above the BOM here https://github.com/jbilander/SDBox-v2/#bom-rev-2a Firmware is the same as before. Regards

Thanks. Will build a new SPI.DEVICE driver for the Amiga and share results here.

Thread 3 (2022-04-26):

Provide Gerber files for PCB manufacturing services

germanviscuso, 2022-04-26:
Services like PCBway or JLCpcb expect Gerber file to start the PCB production, Can you provide them besides KiCad? Steps are here:
https://www.pcbway.es/helpcenter/technical_support/Generate_Gerber_file_from_Kicad.html
https://support.jlcpcb.com/article/44-how-to-export-kicad-pcb-to-gerber-files

jbilander, 2022-04-26:
Did you check under _Releases_ tab?

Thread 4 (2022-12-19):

Amiga 1000 issues

ami-commo-fan, 2022-12-19:
I already submitted on Nicolas par-to-spi page, but so far no response, so reporting here as well.
Does anyone succeeded to have working unit on Amiga 1000?
I have following issue running the adapter on the Amiga 1000.
The symptoms are the sdcard drive appears and disappears constantly for about 20 seconds and after is no longer accessible. All the time CPU usage is at maximum.
When using the same adapter on amiga with standard serial port, all works well.
I was checking the connections and all the signals needed are present on A1000 par. port so I do not understand why it is not working as expected.
Could that be similar driver issue that prevented working on A3000/4000 and was fixed lately?
I tried both 2.0 and 2.1 drivers both behave the same.

salocinx, 2022-12-20:
The problem on the A4000D was a timing issue (should be resolved in 2.1 release of the driver). The A3000D did not even initialize any MicroSD card without pull-up resistors on the parallel port data lines. Do you have pull-up resistors at the parallel port data lines in your specific SDBox?

Then, someone else reported a different issue with the A1000, some initialization issue. Finally he found out, that the 68010 CPU is incompatible with the current driver. Reverting to the original 68000 CPU resolved the issue. What CPU type you are using (68000 / 68010 or any accelerator) ?

I myself have tested the SDBox on the A1000 and I did not have any troubles with the latest driver revision 2.1, even without the pull-up resistors.

Does your SDBox has a female parallel port connector or do you use any intermediate adapter to connect a standard SDBox to the special A1000 male parallel port?

ami-commo-fan, 2022-12-20:
Actualy I made the sdbox for friend (with A1000). I built according the par-spi-scheme, so there is no pull-up resistors. I built with the female connector, but tested myself on my amigas (with gender-changer) and it worked. Of course I did not connect the +5V line which is different on both parallel ports. I expect he has a stock machine, but will let him know about the 010 incompatibility.
So I think good to try is the pull-ups. Is it 10k resistor from VCC (+5V) to each 2-9 dataline?

salocinx, 2022-12-20:
Yes, I pulled-up all the parallel port pins D0-D7, ACK, BUSY, POUT and SEL. But if I remember correctly, this was not needed on the A1000, only the A3000. Even the [SDBox v1](https://github.com/jbilander/sdbox) worked fine on the A1000. Jorgen later added level shifting ICs to the design in order to have a better translation between 3V3/5V for the SPI signals (MOSI/MISO/etc) between the SD card and ATMEGA micro controller (cp. [SDBox v2](https://github.com/jbilander/sdbox-v2)).

However, before you turn your hardware design inside out, I would first test with some other MicroSD card brands. I always made good experiences with SanDisk so far, lots of other brands currently don't work reliably. Maybe Jorgen can tell you what brand he used successfully (it was something other than SanDisk, but I cannot remember).

ami-commo-fan, 2022-12-20:
Ok, thanks for suggestions. The SDBox you tested ok with A1000 was just wired without the level shifter?

salocinx, 2022-12-23:
> Ok, thanks for suggestions. The SDBox you tested ok with A1000 was just wired without the level shifter?

As far as I remember, yes. I tested SDBox v1, which is without level shifter, and it worked on my A1000 with a SanDisk (4GB FAT/FAT16 partition).

jbilander, 2022-12-26:
On SDBox-v1 there is an IC on the SD Card Adapter-board that does the translation. I think it's an 74LVC125A that is fed with 3.3V. It might be that the MISO driven from the MicroSD drop too much to indicate a HIGH on the 74LVC125A or that the voltage level towards the ATMega is too low, however 3.3V should be enough for indicating a HIGH on the ATMega and also on the 74LVC125A. Anyway you have to put a pull-up resistor like SukkoPera did here:
https://github.com/jbilander/sdbox/issues/2#issuecomment-767763618

More info on the Catalex Micro SD Card Adapter here:
https://circuitstate.com/tutorials/interfacing-catalex-micro-sd-card-module-with-arduino/
https://forum.arduino.cc/index.php?topic=604921.msg4314215#msg4314215

Alectronics, 2023-08-05:
This v2B mini SDbox never worked reliable, not even with the newest drivers with the multilanguage FAT95 files on them.
After which my SD0: CF drive was gone and disabled.

So more trouble here sadly. Why I placed the old FAT95 back and removed that Mini micro SD Box driver  version. Its useless to try to fix something so unreliable.

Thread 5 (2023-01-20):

USB port - mechanical strength

SanguineBrah, 2023-01-20:
The location of the USB port on the underside of the board means that any cables hanging down are potentially levering the port away from the board and are in danger of ripping the pads right off the PCB (ask me how I know). A through-hole part would be stronger although I assume SMT was chosen to make routing easier. Another option would be to include slots either side of the port so that a cable tie could be used to secure it - it looks like this would only need one trace to be moved on the top side.

jbilander, 2023-01-20:
Hi, Yes there are some improvements that can be made, perhaps switch to a USB-C jack and also the SD-card holder could have been moved a bit further out on the PCB-edge so that it would be easier to grab hold of the MicroSD-card when you have the 3D-printed case on. However I currently have no need for more SDBoxes myself so right now that is not something I will do right now. It is open source so anyone who wants to improve the design can do so, but remember to share it back to the community afterwards.

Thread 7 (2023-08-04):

Build mini version 2B with smd components and Atmega328p chip. But all sd cards are No dos recognised!

Alectronics, 2023-08-04:
Only the card change is detected but never any transfer or data led activity visible. Only my green power led is always lit.
Tried every driver/boot version I could think of on my Amiga 1200 but the SD reader interface is very unreliable and never works as was expected. I also tried a 2GB fat and fat32 formatted original Sandisk microSD card same issue. No-dos disk.
Boards were made by PCBway according to the v2b gerber files but all was a waste of time and money.
Many other buyers/makers made this same comment. And the solutions given are always useless. After they gave up on this product!
This interface in case of these hopeless issues should have many more presented diagnostic info to check on like scope diagrams or logic analyzer diagrams to fix a not working interface.

Luckily my CF adapter interface always works splendidly to transfer files between my PC and Amiga. Including a perfect working internal CF Windows boot 'hdd'.

jbilander, 2023-08-05:
Hi, I have built several v2 and Mini devices with PCBs from JLCPCB and they all work perfectly fine with the latest fw and driver:

https://github.com/jbilander/amiga-par-to-spi-adapter/

There is no problem with the hardware. It has been tested by many people by now with the above firmware and it works even on a wirewrap thingie.

There has been reports of some MicroSD-cards not working properly and problems on the A1000.
https://github.com/niklasekstrom/amiga-par-to-spi-adapter/issues/8

And of course the usual thing with checking the CIAs with ATK and put pull-ups on the parallel-port control- and data-lines (required for some A3000 it seems)

_"This interface in case of these hopeless issues should have many more presented diagnostic info to check on like scope diagrams or logic analyzer diagrams to fix a not working interface."_

So why do you not make them? Remember this is an open source hobby project. Everything is there for anyone to dig in and help to improve it. Contribute nothing, expect nothing!

Alectronics, 2023-08-05:
Yes I understand but sorry Jorgen. I already wasted over 2 weeks figuring out why it won't work invain.

I even questioned the Amiga 1200 parallel port being defect why I also build today a parallel loop port tester and found out that it was working 100% fine!

So nothing is defect only the still not working v2B mini sd card reader/writer must be defect or badly designed.
Sadly I can't fix a problem that is made by others who obviously spended a lot of time to try to build such genious device that most of the time gives compatibility issues if it works!

Albert.

________________________________
Van: Jorgen Bilander ***@***.***>
Verzonden: zaterdag 5 augustus 2023 11:53
Aan: jbilander/SDBox-v2 ***@***.***>
CC: Alectronics ***@***.***>; Author ***@***.***>
Onderwerp: Re: [jbilander/SDBox-v2] Build mini version 2B with smd components and Atmega328p chip. But all sd cards are No dos recognised! (Issue #7)

Hi, I have built several v2 and Mini devices with PCBs from JLCPCB and they all work perfectly fine with the latest fw and driver:

https://github.com/jbilander/amiga-par-to-spi-adapter/

There is no problem with the hardware. It has been tested by many people by now with the above firmware and it works even on a wirewrap thingie.

There has been reports of some MicroSD-cards not working properly and problems on the A1000.
niklasekstrom/amiga-par-to-spi-adapter#8<https://github.com/niklasekstrom/amiga-par-to-spi-adapter/issues/8>

And of course the usual thing with checking the CIAs with ATK and put pull-ups on the parallel-port control- and data-lines (required for some A3000 it seems)

"This interface in case of these hopeless issues should have many more presented diagnostic info to check on like scope diagrams or logic analyzer diagrams to fix a not working interface."

So why do you not make them? Remember this is an open source hobby project. Everything is there for anyone to dig in and help to improve it. Contribute nothing, expect nothing!

—
Reply to this email directly, view it on GitHub<https://github.com/jbilander/SDBox-v2/issues/7#issuecomment-1666458075>, or unsubscribe<https://github.com/notifications/unsubscribe-auth/AUFU6ZFT2K7BMBLWEWJBBPDXTYJ3DANCNFSM6AAAAAA3EL755E>.
You are receiving this because you authored the thread.Message ID: ***@***.***>

jbilander, 2023-08-05:
So you need to do basic troubleshooting:

* Does the CIA work correctly with ATK (Amiga Test Kit)
* Is 5V-powering to the device looking good?
* Is 3.3V generated correctly to the MicroSD-card holder VCC-pin?
* Do you have activity on the MISO-line?
* Do you have activity on the MOSI-line?
* Do you have activity on the Parallel-port data and control lines? Pull-ups might be needed.
* Is the latest firmware flashed to the ATMega328p with fuses correctly set?
* Is the latest driver spisd.device put in the Devs folder on the Amiga?
* Is the correct version of the SD0 Mount file used for your WB-version on the Amiga?
* Is the latest fat95 driver copied to the Amiga?
* Does the 16 MHz clock looks ok going to the ATMega input pin?
* Do you have any solder bridges?
* Are you using a known good MicroSD-card?
* Does the device show the same error on another Amiga?
* Is the MicroSD-card properly FAT/FAT32-formatted?
etc, etc...

Alectronics, 2023-08-05:
Thanks for your fast reply Jorgen. But I thought my SDbox 2.b interface was complete and didn't need any pullups or modification?
What more do I also need to pullup because those smd 4R10K pullups were already on the miniSD reader board to accomplish that?

Albert.

________________________________
Van: Jorgen Bilander ***@***.***>
Verzonden: zaterdag 5 augustus 2023 12:34
Aan: jbilander/SDBox-v2 ***@***.***>
CC: Alectronics ***@***.***>; Author ***@***.***>
Onderwerp: Re: [jbilander/SDBox-v2] Build mini version 2B with smd components and Atmega328p chip. But all sd cards are No dos recognised! (Issue #7)

So you need to do basic troubleshooting:

  *   Does the CIA work correctly with ATK (Amiga Test Kit)
  *   Is 5V-powering to the device looking good?
  *   Is 3.3V generated correctly to the MicroSD-card holder VCC-pin?
  *   Do you have activity on the MISO-line?
  *   Do you have activity on the MOSI-line?
  *   Do you have activity on the Parallel-port data and control lines? Pull-ups might be needed.
  *   Is the latest firmware flashed to the ATMega328p with fuses correctly set?
  *   Is the latest driver spisd.device put in the Devs folder on the Amiga?
  *   Is the correct version of the SD0 Mount file used for your WB-version on the Amiga?
  *   Is the latest fat95 driver copied to the Amiga?
  *   Does the 16 MHz clock looks ok going to the ATMega input pin?
  *   Do you have any solder bridges?
  *   Are you using a known good MicroSD-card?
  *   Does the device show the same error on another Amiga?
  *   Is the MicroSD-card properly FAT/FAT32-formatted?
etc, etc...

—
Reply to this email directly, view it on GitHub<https://github.com/jbilander/SDBox-v2/issues/7#issuecomment-1666466628>, or unsubscribe<https://github.com/notifications/unsubscribe-auth/AUFU6ZGC2ZL4KJ2MABJRHGDXTYOTDANCNFSM6AAAAAA3EL755E>.
You are receiving this because you authored the thread.Message ID: ***@***.***>

jbilander, 2023-08-05:
pull-ups should not be needed on the A1200. I think it was required for the A3000.

https://github.com/jbilander/SDBox-v2/issues/4#issuecomment-1359937696
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
Alectronics, 2023-08-06:
I've thrown this crap product aside after the miniSDbox continuesly failed to work. And after all this time of wasted testing also the micro-usb connector broke of the tiny copper layers for the third time. Which probably wouldn't have happened if it finally was working and safely ready build in the DB25 connector case.

Those that got lucky with building this Amiga miniSDBox reader must have been extremely fortunate or they could find the right firmware for it because I never had so much trouble with finding the right firmware or getting a device working before!
And those people in the happy videos obviously got it ready tested including the properly working library files. Because to me and other buyers who also claimed their ready bought Amiga parallel port reader never worked it looks like this unfinished project was designed to fail.

________________________________
Van: Albert van bemmelen ***@***.***>
Verzonden: zondag 6 augustus 2023 00:16
Aan: jbilander/SDBox-v2 ***@***.***>
Onderwerp: Re: [jbilander/SDBox-v2] Build mini version 2B with smd components and Atmega328p chip. But all sd cards are No dos recognised! (Issue #7)

Sorry I already tried 6 different cards of which only one was microSD Sandisk 2GB. And the latter shortly worked with a lot of errors but now does nothing anymore.
My windows computers have no problem with reading any of them! Fat32 formatted. Only the miniSDbox v2b refuses to see them!

And sorry can't do anything with this info, since there is no driver FW =>

https://github.com/jbilander/amiga-par-to-spi-adapter

And I probably already tried all the versions 2 that had.

I'm pretty sure that it must be some software problem with the libraries or drivers. If it is not about port line pullups.

Albert.

________________________________
Van: Jorgen Bilander ***@***.***>
Verzonden: zondag 6 augustus 2023 00:04
Aan: jbilander/SDBox-v2 ***@***.***>
CC: Alectronics ***@***.***>; Author ***@***.***>
Onderwerp: Re: [jbilander/SDBox-v2] Build mini version 2B with smd components and Atmega328p chip. But all sd cards are No dos recognised! (Issue #7)

Well, if you have only tried ONE type of MiroSD-card and you say that card now does not even work in your PC or Mac. Maybe you should start thinking that it would be smart to try another card? Perhaps one listed here since they are verified to work. Makes me think you are not troubleshooting anything at all, just trolling.

jbilander/sdbox#15 (comment)<https://github.com/jbilander/sdbox/issues/15#issuecomment-1120407423>

The activity LED should work if you build from sources here:

Sorry can't do anything with this onfo, there is no driver FW =>

https://github.com/jbilander/amiga-par-to-spi-adapter

specifically this is the change:
***@***.***<https://github.com/niklasekstrom/amiga-par-to-spi-adapter/commit/aeaf351bd57fc0b75dae18e1f8b91ef14cbc8c00>

Niklas' code/release does not include code driving the activity LED. Anyway you should see activity on the MISO and MOSI lines and of course the parallel lines during MOUNT if you troubleshoot with a logic analyser or oscilloscope. I have already given you a list of what to start checking.

—
Reply to this email directly, view it on GitHub<https://github.com/jbilander/SDBox-v2/issues/7#issuecomment-1666620611>, or unsubscribe<https://github.com/notifications/unsubscribe-auth/AUFU6ZHBPLYGFGG3X7E6OVDXT27NTANCNFSM6AAAAAA3EL755E>.
You are receiving this because you authored the thread.Message ID: ***@***.***>

jbilander, 2023-08-06:
Not all people are made for DIY. Perhaps in your next life. Who knows, you might even be talented enough to run a bat file to compile a driver. Let's hope for that.

Alectronics, 2023-08-06:
Not all people present the ready and working upgrade firmware either LOL. Because all seen Github pages failed presenting those files. And the many firmware changes you previously showed made clear that only the insiders know what it is all about.
If I only knew  WHAT bat file is the correct REALLY working version? Because all previous boot disks and version 2 files completely failed working!
________________________________
Van: Jorgen Bilander ***@***.***>
Verzonden: zondag 6 augustus 2023 12:03
Aan: jbilander/SDBox-v2
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

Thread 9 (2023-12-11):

T

jbrandstetter, 2023-12-11:
Hi,

my overall goal is to be able to transfer larger files (i.e. larger than what fits on a floppy) to my Amiga.

So far I've tried CF to PCMCIA and the SDBox v2 but can't get neither to work.

My situation is as follows:

I have an Amiga 600 with:

*   3.1 RM, Kickstart 40.63, WB 40.42
*  a Furia accelerator
*   a 604N memory expansion
*  an internal Gotek
*  an SD2IDE Converter / Adapter
* an SDBox v2 from amigastore.eu powered by an external power source, with a supplied SD Card
* a plipbox ethernet adapter (which is working)
* a CF to PCMCIA adapter also from amigastore.eu

On the software side I have:

*   Installed the SDBox v2 drivers supplied by amigastore.eu
*   The following files in Devs/
    * compactflash.device
    * spisd.device
    * nothing in Devs/DOSDrivers/
*   FAT95 in L/
*   a Mountlist for SD0:

        FileSystem     = l:fat95
        Device         = spisd.device
        Unit           = 0
        Flags          = 0
        LowCyl         = 0
        HighCyl        = 0
        Surfaces       = 1
        BlocksPerTrack = 1
        BlockSize      = 512
        Reserved       = 0
        Buffers        = 20
        BufMemType     = 1
        BootPri        = 0
        StackSize      = 4096
        Priority       = 5
        GlobVec        = -1
        DosType        = 0x46415401

This mountlist is currently sitting in my "GAMES" partition. Then I do:

* mount GAMES:SD0 -> that works
* cd SD0: gives either "bad number" or the red light on the box lights up and Workbench is frozen

Any pointers on what I'm doing wrong?

Thanks,

Johannes

jbilander, 2023-12-11:
Hi, if their V2 is the same as my V2-design that works with Niklas' firmware I don't know since they don't share and follow the copyleft license. They should do the support at least when they take open designs without even giving a heads-up. I guess for them it's more important to make money. With that said there is a bugfixed driver here that has much better compatibility with different Micro-SD-cards now (thanks to Patrik) that you could try: spisd.device.zip ,or build your own from source.

https://github.com/niklasekstrom/amiga-par-to-spi-adapter/pull/9

jbrandstetter, 2023-12-11:
Oh wow, didn't know they were not playing nicely. Will consider that in the future. Thanks for the link to the other driver. Will give that a try!

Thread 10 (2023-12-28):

System hangs on Amiga 600 + classic Pistorm

Topaz750, 2023-12-28:
Hello,

I recently purchased the SDBox V2 from Amigastore.eu, but I'm encountering difficulties in getting it to function with my A600 Pistormed (Pi3A+). After installing the drivers, the system freezes during boot-up, indicated by a red light on the SDBox. I attempted using spisd.device version 2.3, but faced the same issue. My tests were conducted on a clean installation of AmigaOS 3.2.1, which was booted from the internal IDE port using a compact flash card, and also with Amikit V12 running from the PiStorm SD card.

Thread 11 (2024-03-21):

Missing newstyle.h

nbdy32, 2024-03-21:
HI, trying to build a new spisd.device, but there is a missing file ...

newstyle.h

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

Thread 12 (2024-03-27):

Access speed issue

martinpgrayson, 2024-03-27:
Hi all - bought a SDBoxV2 from Amigastore.eu. Its fantastic, such a cool device, thank you so much for creating it. Everything works, however, I just have a question about the initial speed when calling cd SD0: after mounting. On my Amiga 500 Rev6A it takes a long time, like between 1-2 minutes. I was wondering if there are things I can try. could it be the SDCard? I am using the drivers provided from this repo, but could it be those? Could it be my amiga?

My setup is very similar to the demo in this video:
https://www.youtube.com/watch?v=VQdrOjCI9As&t=75s

I have WB1.3 copied on to the SD card, and I followed these instructions to get it to boot to that copy:
https://exxosforum.co.uk/forum/viewtopic.php?t=6148

Before moving to booting WB1.3 from the SD card, I also tested with the Mount_SDCard script added do my WB floppy, just like this video:
https://youtu.be/mpZu9q7MV5I?si=iGDSSpGcRZjtWcR9&t=503

In the video, you can see it mounts an appears in about 20-30 seconds.

The last thing I noticed is that in other demo videos, when you eject the SD card, the drive disappears from the WB screen, and then reappears when you put the SD card back in - so it feels like I have done something wrong - wrong driver setup maybe?

Any help would of course be amazing, but I also appreciate this is already doing something clever, and it at least works, but would love to get the speed up just a bit.

jbilander, 2024-03-27:
Hi,

I have no affiliation with any Amiga store selling devices, nor does Niklas, and this is only a non-profit hobby project, so I'm not so keen on doing their support while they cash-in on sales not even giving a heads-up that they started making and selling devices, but what I can say is mounting the SD-Card should not take that long. Are you using the latest spisd.device driver built from here?
https://github.com/jbilander/amiga-par-to-spi-adapter

instructions here:
https://eab.abime.net/showpost.php?p=1601771&postcount=58

or you can use the pre-built one from Niklas' repo here, but then you won't have the LED blink activity working. That code-snippet is only added to my fork of the repository.
https://eab.abime.net/showpost.php?p=1602029&postcount=60

Anyway, thanks for the appreciation.

martinpgrayson, 2024-03-28:
Hi @jbilander  - thanks for replying. I really appreciate the pointers of thigs to try, even though this was bought through a store, and I totally agree that its not good to cash in on open source projects. I don't have any hardware skills, so that is why I end up paying for these pre-built things. I was pleased to see your name on the box it came in, but clearly that is all they are doing. I downloaded the pre-built driver from Niklas' repo, and the card still took the same amount of time to load. If you have any other suggestions you are happy to share, I will very happily try them. I have some software skills, so can compile stuff. I could even flash firmware if its not too tricky... I also accept it might be my Amiga 500 (I do have a 500+ I can test on too to rule that out), and otherwise, I am happy to go back to the store and register a complaint there. Again, amazing, amazing project - I was not keen to go down the IDE68K route, as that is an internal card, and I didnt really have a plan on how to transfer files, but then I came across this (in Amiga Addict) and thought this is absolutely perfect.

patrikaxelsson, 2024-12-12:
The fat95 filesystem driver will load the complete FAT table from the SD-card on mount time, which can be several MB in size if conditions are wrong - say large card 16GB+ and formatted with Windows or OS X built-in FAT formatter. Generally a smaller card or smaller partition, in combination with the largest FAT cluster size will help as that reduces the FAT table size.

The official [SD Card Formatter](https://www.sdcard.org/downloads/formatter/) is an easy way to format an SD card with the largest cluster size.

I would not recommend more than 4GB card size if you are after reasonably quick mounts.

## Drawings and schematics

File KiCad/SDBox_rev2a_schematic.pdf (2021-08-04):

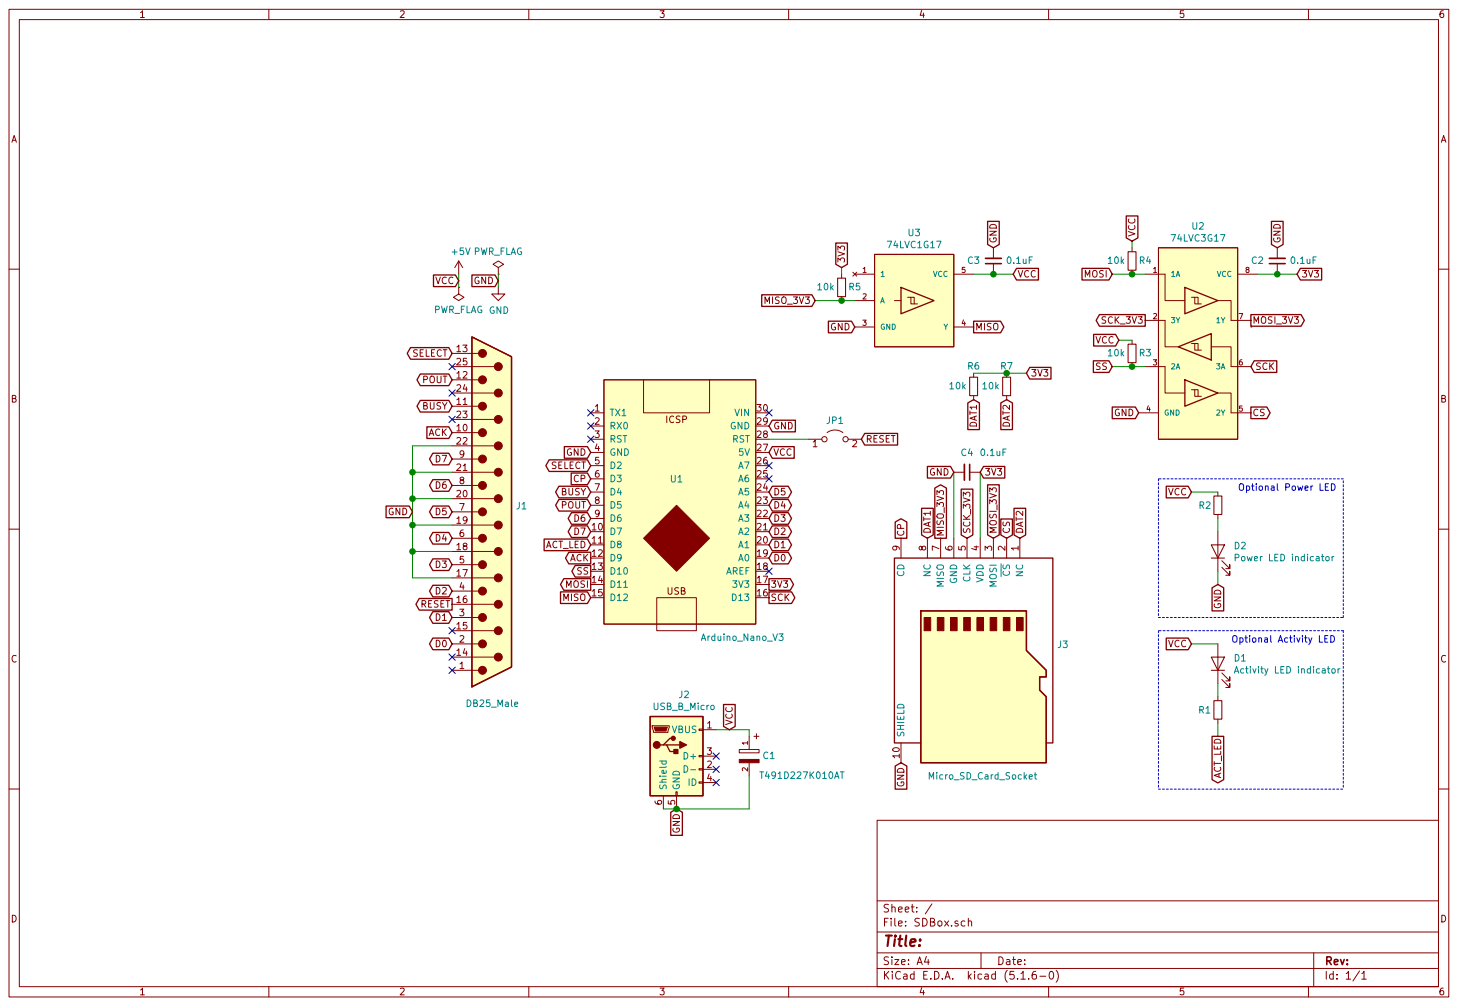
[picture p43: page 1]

Id: 1/1 Title: File: SDBox.sch Sheet: /

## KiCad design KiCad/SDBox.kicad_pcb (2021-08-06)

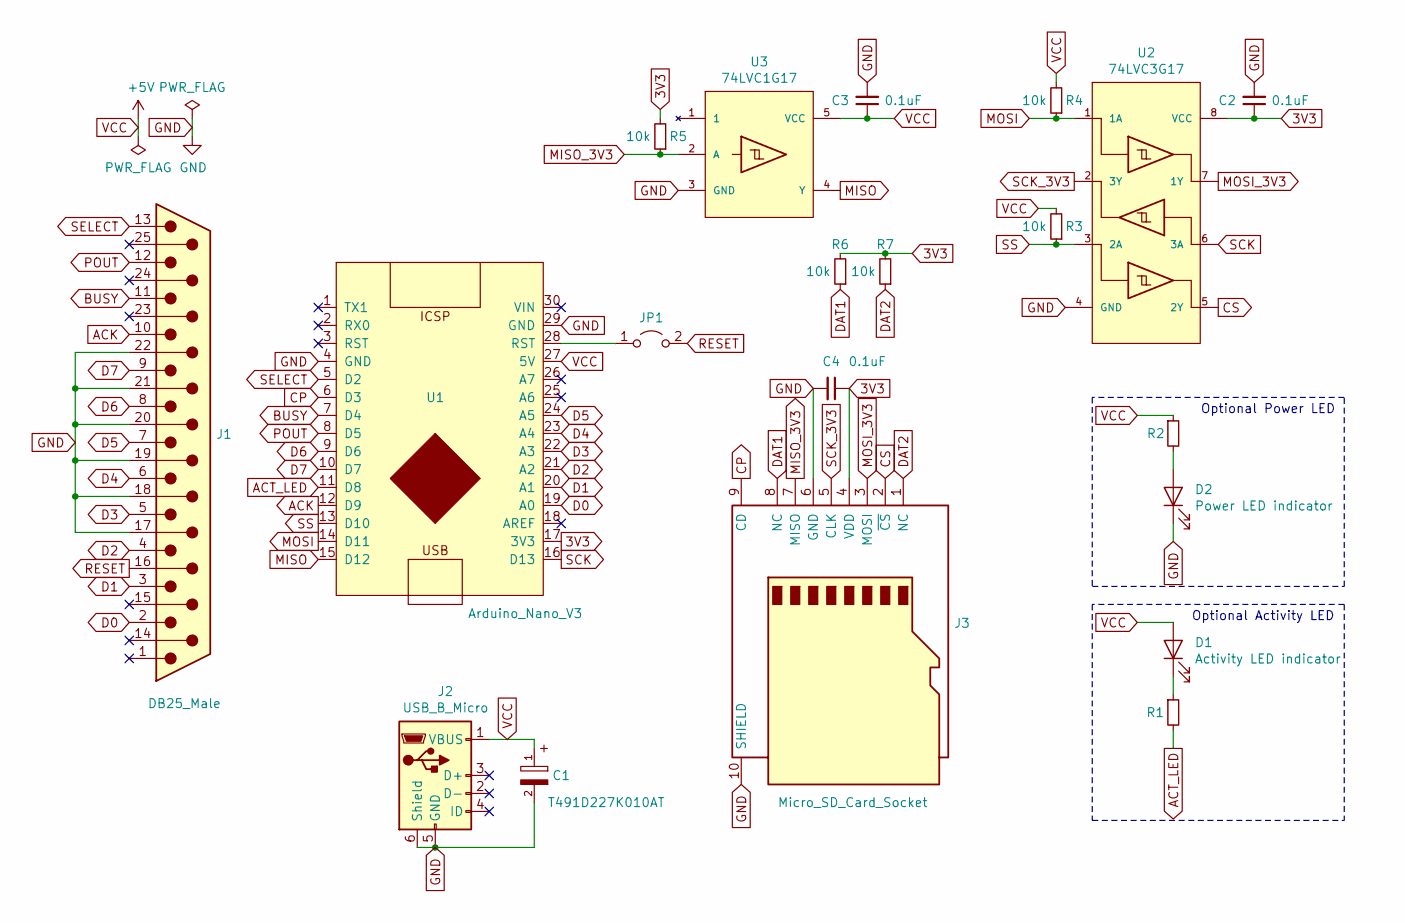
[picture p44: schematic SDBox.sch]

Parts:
C1: T491D227K010AT; CAPMP7343X430N
C2, C3, C4: 0.1uF; C_0805_2012Metric_Pad1.15x1.40mm_HandSolder
D1: Activity LED indicator; LED_D3.0mm
D2: Power LED indicator; LED_D3.0mm
J1: DB25_Male; DSUB-25_Male_EdgeMount_P2.77mm
J2: USB_B_Micro; USB_Micro-B_Unknown_5s_SMT
J3: Micro_SD_Card_Socket; GCT-MEM2055-00-190-01-A
JP1: Jumper_2_Open; R_1206_3216Metric_Pad1.42x1.75mm_HandSolder
R1, R2: 150; R_1206_3216Metric_Pad1.42x1.75mm_HandSolder
R3, R4, R5, R6, R7: 10k; R_1206_3216Metric_Pad1.42x1.75mm_HandSolder
U1: Arduino_Nano_V3
U2: 74LVC3G17; TSSOP-8_3x3mm_P0.65mm_Custom_Handsoldering
U3: 74LVC1G17; SOT-353_SC-70-5_Custom_Handsoldering

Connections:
3V3: C2.1, C4.1, J3.4 (VDD), R5.2, R6.2, R7.2, U1.17 (3V3), U2.8 (VCC)
ACK: J1.10, U1.12 (D9)
ACT_LED: R1.2, U1.11 (D8)
BUSY: J1.11, U1.7 (D4)
CP: J3.9 (CD), U1.6 (D3)
CS: J3.2 (~CS), U2.5 (2Y)
D0: J1.2, U1.19 (A0)
D1: J1.3, U1.20 (A1)
D2: J1.4, U1.21 (A2)
D3: J1.5, U1.22 (A3)
D4: J1.6, U1.23 (A4)
D5: J1.7, U1.24 (A5)
D6: J1.8, U1.9 (D6)
D7: J1.9, U1.10 (D7)
DAT1: J3.8 (NC), R6.1
DAT2: J3.1 (NC), R7.1
GND: C1.2, C2.2, C3.2, C4.2, D2.1 (K), J1.17, J1.18, J1.19, J1.20, J1.21, J1.22, J2.5 (GND), J2.6 (Shield), J3.6 (GND), J3.10 (SHIELD), U1.4 (GND), U1.29 (GND), U2.4 (GND), U3.3 (GND)
MISO: U1.15 (D12), U3.4 (Y)
MISO_3V3: J3.7 (MISO), R5.1, U3.2 (A)
MOSI: R4.1, U1.14 (D11), U2.1 (1A)
MOSI_3V3: J3.3 (MOSI), U2.7 (1Y)
unnamed: D1.1 (K), R1.1
unnamed: D2.2 (A), R2.2
unnamed: JP1.1 (A), U1.28 (RST)
POUT: J1.12, U1.8 (D5)
RESET: J1.16, JP1.2 (B)
SCK: U1.16 (D13), U2.6 (3A)
SCK_3V3: J3.5 (CLK), U2.2 (3Y)
SELECT: J1.13, U1.5 (D2)
SS: R3.1, U1.13 (D10), U2.3 (2A)
VCC: C1.1, C3.1, D1.2 (A), J2.1 (VBUS), R2.1, R3.2, R4.2, U1.27 (5V), U3.5 (VCC)

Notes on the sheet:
Optional Activity LED
Optional Power LED

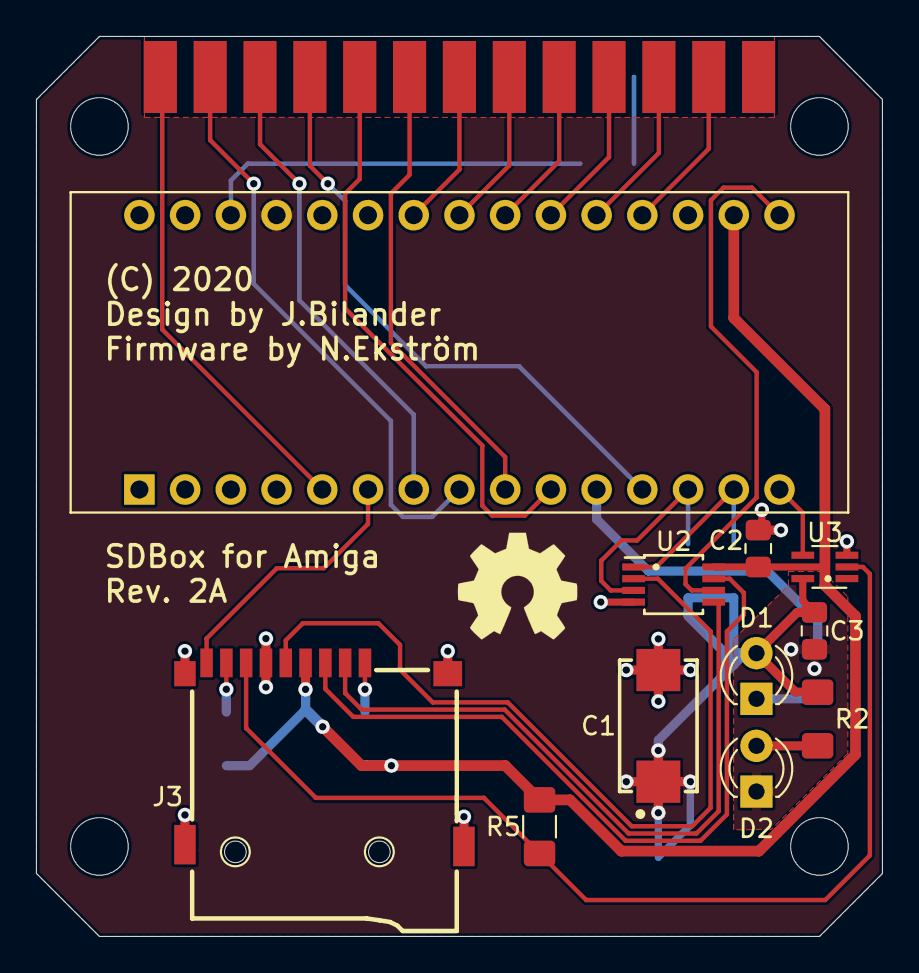
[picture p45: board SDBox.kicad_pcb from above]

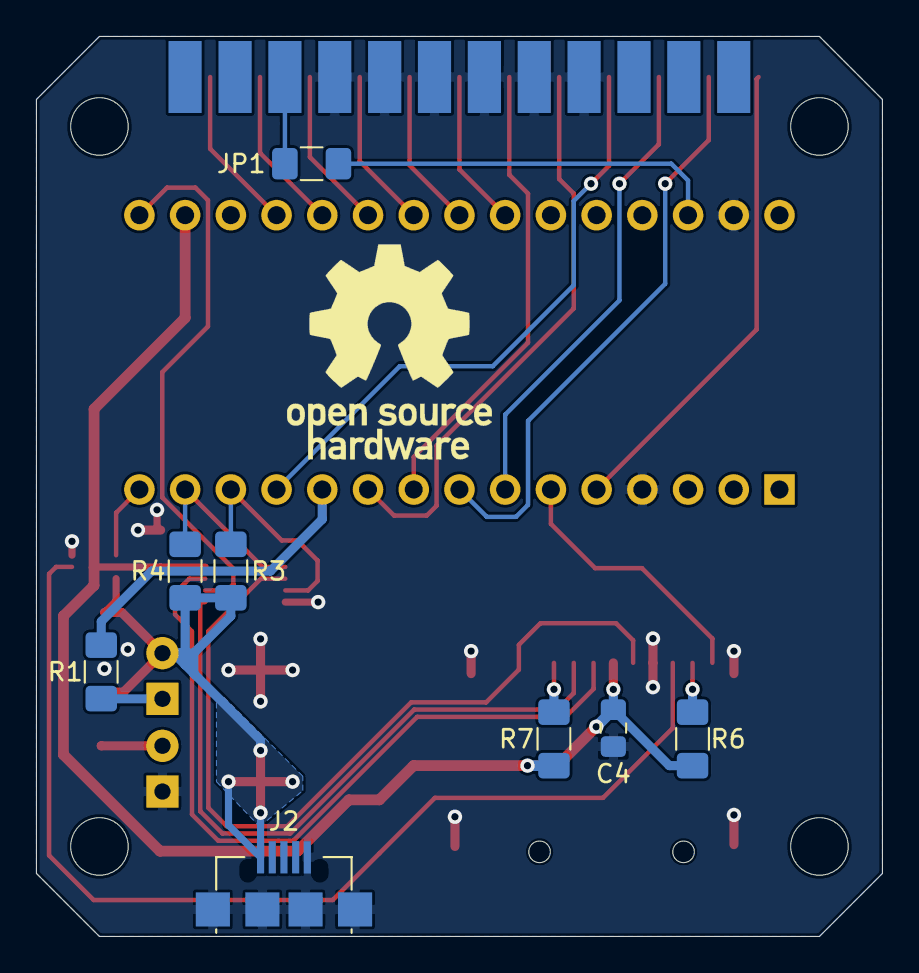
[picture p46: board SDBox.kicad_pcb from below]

Board: 2 copper layers, 47.0 x 50.0 mm, 20 parts (8 on the bottom side), 31 nets.

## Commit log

2021-08-04 added footprints
2021-08-04 added KiCad files
    [SDBox.kicad_pcb, SDBox.sch]
2021-08-04 added schematic pdf
2021-08-06 small improvement 3V3-routing
    [SDBox.kicad_pcb]
2021-09-30 Added source file SDBox-v2 case made in DesignSpark Mechanical 5.0
2021-09-30 Added source file SDBox-text made in SketchUp Make 2017
    [SDBox-v2_text.skp]
2021-09-30 Added generated stl files for 3D-printing SDBox-v2 case
    [SDBox-v2_case_bottom.stl, SDBox-v2_case_top.stl]

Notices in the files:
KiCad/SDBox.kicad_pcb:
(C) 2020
